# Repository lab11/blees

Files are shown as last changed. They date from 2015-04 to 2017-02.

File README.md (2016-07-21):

BLEES
=====

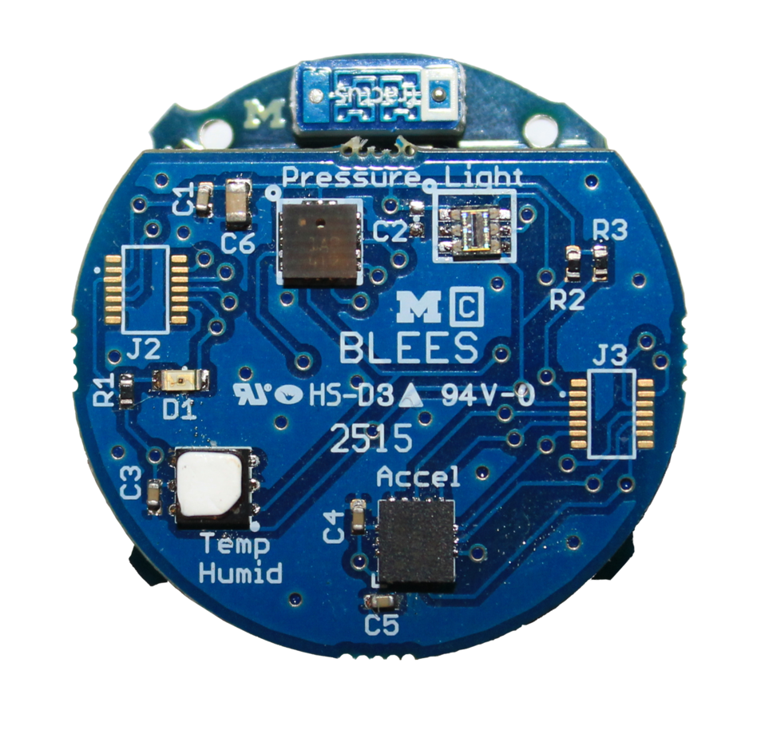
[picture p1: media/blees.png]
BLEES

BLEES: Bluetooth Low Energy Environment Sensors.
<br /><br />
BLEES is a 1 inch round sensor tag for sensing the ambient environment. It monitors
temperature, humidity, light, pressure, and movement and reports its readings
over BLE.
<br /><br /><br />

Hardware
--------
The BLEES hardware is a small, once inch round sensor board that mounts onto a [Squall](https://github.com/helena-project/squall) BLE sensor tag. The board 
currently has four sensors:

1. Temperature and Humidity (Si7021)
2. Pressure (LPS331AP)
3. Light (TSL2561)
4. Accelerometer (ADXL362)

The BLEES hardware is located in the `hardware` directory, where you can find
the Eagle design files.

Software
--------
The [Squall](https://github.com/helena-project/squall) uses the software
located in the `software` directory. Follow the directions in the [nrf5x-base Readme]
(http://github.com/lab11/nrf5x-base#program-a-nrf51822) to
get your machine set up to build and flash the Squall.

The primary application is
[`software/apps/blees`](https://github.com/lab11/blees/tree/master/software/apps/blees).
This application samples the
sensors and makes this data available as both broadcast advertisements and the
Environmental Sensing Service for a connected device.

Data Reference
--------------
### Advertisement data
BLEES transmits advertisements every 1000 ms containing application data.
[Here's a useful BLE Advertisement
primer](http://www.argenox.com/bluetooth-low-energy-ble-v4-0-development/library/a-ble-advertising-primer/).
The advertisements come in two forms: environmental data and eddystone.
Advertisements alternate between the two evenly.

The environmental data advertised is same data as is available through the
environmental sensing service, but broadcast so several nearby devices can
access it concurrently. The data includes, in order, four bytes for pressure,
two bytes for humidity, two bytes for temperature, two bytes for light
illuminance, and one byte for acceleration state. An example application that
collects BLE advertisements from BLEES devices and displays the data can be
found at `data_collection/advertisements/blees_adv.js`

[Eddystone](https://github.com/google/eddystone) is a protocol for connecting
BLE devices to Internet resources. BLEES advertises the URL of an application
that can be interpreted by the Summon framework in order to automatically
generate a user interface. (see next heading)

### Environmental Sensing Service
BLEES is also connectable and supports the Environmental Sensing Service. While
connected to, it continues to advertise, but only one connection at a time is
allowed. The environmental sensing service is defined by the
[BLE SIG](https://www.bluetooth.org/en-us/specification/assigned-numbers/environmental-sensing-service-characteristics).

Summon App
----------
[Summon](https://github.com/lab11/summon) is a UI application for BLE devices.
Rather than requiring every user
to install a new app for every BLE device, Summon allows BLE devices to
point to their own HTML/JS based interface and loads it in a single
application. BLEES supports the summon architecture and provides
a Summon application.

Cloning
-------
To clone both this repository and the required submodules,
clone with the `--recursive` option: 
`git clone --recursive git@github.com:lab11/blees.git`

Otherwise, you can initialize the submodule and keep submodules up to
date by doing `git submodule update --init --recursive`

If you think all of this is ridiculous and git should just handle submodules automatically, use this:
https://gist.github.com/brghena/fc4483a2df83c47660a5

Other Hardware
--------------

Included in this repo are:

### Blink

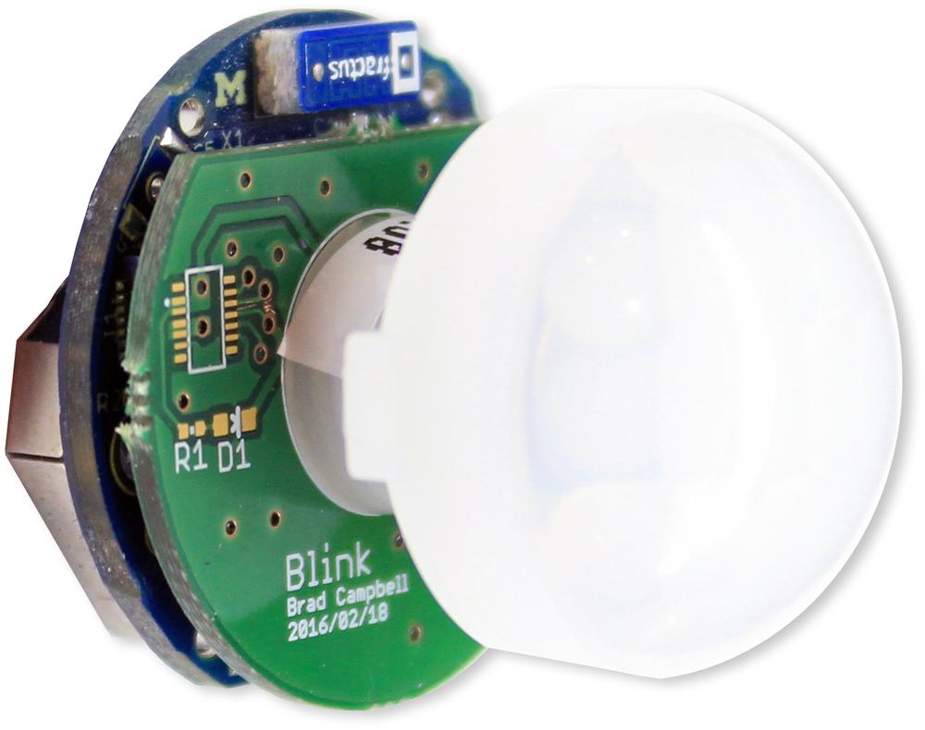
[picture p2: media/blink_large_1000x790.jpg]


Blink is a PIR sensor that is also based on Squall. Like BLEES, it supports Summon.
The nRF51822 app is [here](https://github.com/lab11/blees/tree/master/software/apps/blink).

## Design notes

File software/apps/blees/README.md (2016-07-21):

BLEES App
=========

This app provides the Environmental Sensing Service for BLEES.

Programming
-----------

    make flash ID=c0:98:e5:30:00:01

Advertisement
-------------

BLEES alternates between advertising environmental data and the
[Eddystone protocol](https://github.com/google/eddystone). It works with the
[Summon](https://github.com/lab11/summon) project that provides a browser-based
UI for BLE devices.

### Data Format

Manufacturer specific data in the advertisement:

| Index | Bytes | Description |
| ----- | --- | --- |
| 0 | `0x07` | Length |
| 1 | `0xff` | Header for manufacturer specific data  |
| 2 | `0x02e0` | University of Michigan manufacturer ID |
| 4 | `0x12` | Service identifier for BLEES data |
| 5-8 | `0x00000000` | Pressure in deci-pascals |
| 8-9 | `0x0000` | Humidity in centi-percent |
| 10-11 | `0x0000` | Temperature in centi-degrees Celsius |
| 12-13 | `0x0000` | Light in lux |
| 14 | `0x00` | Acceleration as explained below |
| 15-18 | `0x00000000` | Sequence number |

*Acceleration* is defined as boolean flags with `bit 0` indicating acceleration
in the last minute and `bit 4` indicating current acceleration.

Ex: 0x01 = acceleration in the last minute, but not currently

### Eddystone URL

Change the `PHYSWEB_URL` define to change where the BLEES Eddystone URL points to.

Services
--------

Standard environmental sensing service [ESS](https://www.bluetooth.org/en-us/specification/assigned-numbers/environmental-sensing-service-characteristics)

How To Change Acceleration
--------------------------
main.c:510 - change variable act_thresh to set the activity threshold
main.c:514 - change variable a_time to set the amount of samples required to be above threshold for a trigger

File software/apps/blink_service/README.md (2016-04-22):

Blink App
=========

Advertise Eddystone and manufacturer specific data when motion is detected.

Hardware
--------

Squall with a digital PIR sensor attached to pin 25.

Data Format
-----------

Manufacturer specific data in the advertisement:

| Index | Bytes | Description |
| ----- | --- | --- |
| 0 | `0x07` | Length |
| 1 | `0xff` | Header for manufacturer specific data  |
| 2 | `0x02e0` | University of Michigan manufacturer ID |
| 4 | `0x13` | Service identifier for Blink data |
| 5 | `0x00` | 0 if no motion right now, 1 if motion  |
| 6 | `0x00` | 0 if no motion since last advertisement packet, 1 if motion in that time |
| 7 | `0x00` | 0 if no motion in the last minute, 1 if motion |

Parsed Data Format
------------------

If Blink is used with a [SwarmGateway](https://github.com/terraswarm/urban-heartbeat-kit),
that gateway will be able to parse Blink packets. The resulting JSON object will
be:

```
{
	"device": "Blink",
	"id": "c098e59000xx",
	"current_motion": true|false,
	"motion_since_last_adv": true|false,
	"motion_last_minute": true|false
}
```

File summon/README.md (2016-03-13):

Summon Apps
===========

[Summon](https://github.com/lab11/summon) is a browser for physical things,
and BLEES comes with HTML/JS applications that Summon supports.

- `blees-app`: Full featured app for both reading and configuring BLEES devices.
- `bless-demo`: Pared down version of the full app with less options. Designed
for quicker viewing in a demo setting.

### Blink

Blink also has a Summon app in the `squall-pir` folder.

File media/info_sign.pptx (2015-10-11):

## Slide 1


BLEES

Indoor Ambient Sensing

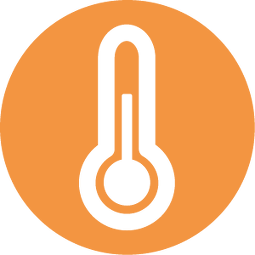
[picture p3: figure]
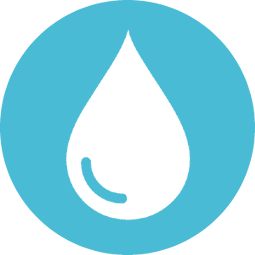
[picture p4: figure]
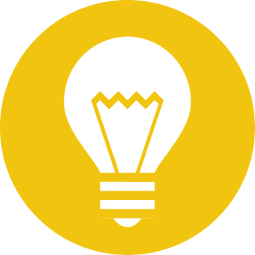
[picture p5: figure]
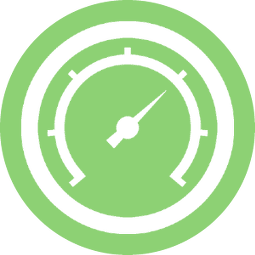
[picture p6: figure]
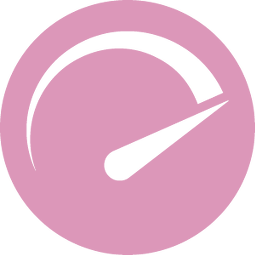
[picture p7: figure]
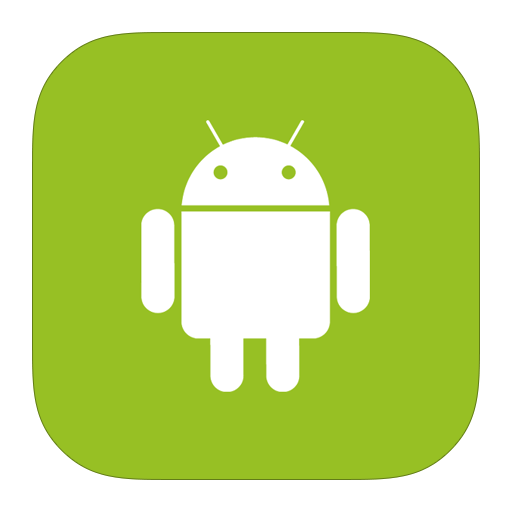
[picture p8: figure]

Download the app!

Summon App for Android

UI discovery for the IoT

Also works with
- PowerBlade
- PolyPoint

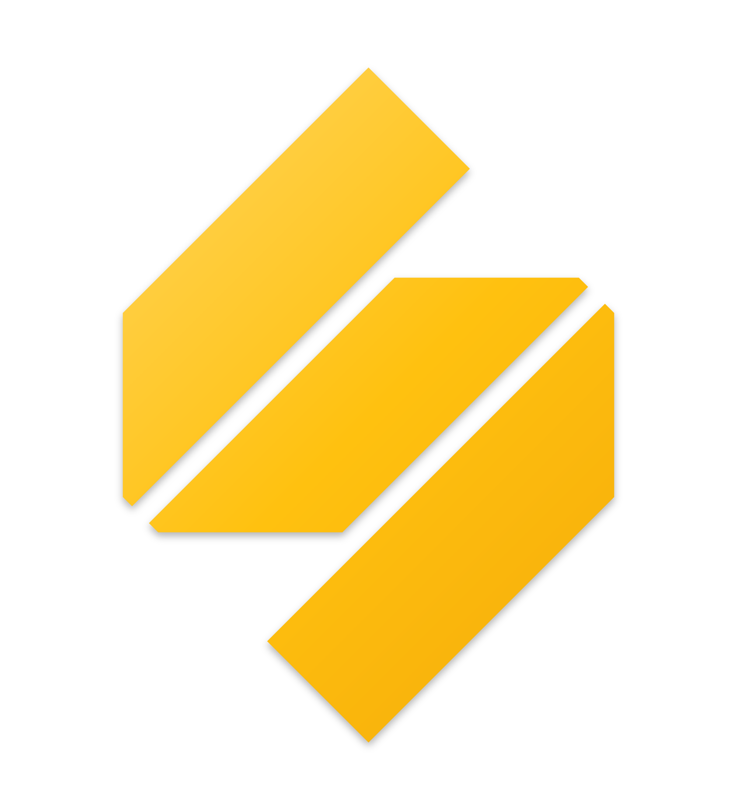
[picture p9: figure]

Search “Summon Lab11” on the Google Play store

https://github.com/lab11/blees
https://github.com/lab11/summon

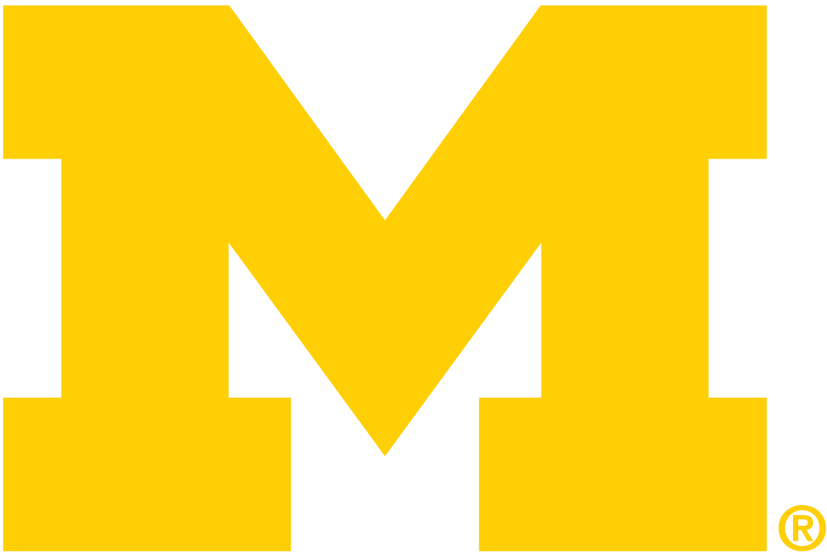
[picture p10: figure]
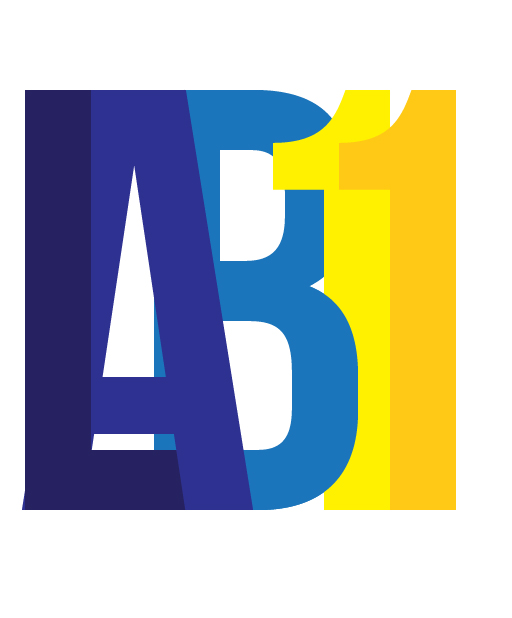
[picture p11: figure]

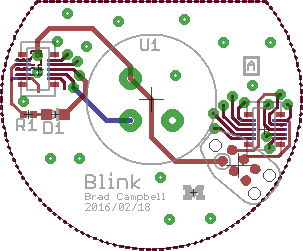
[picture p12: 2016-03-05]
hardware/blink/rev_a/blink_pcb.png

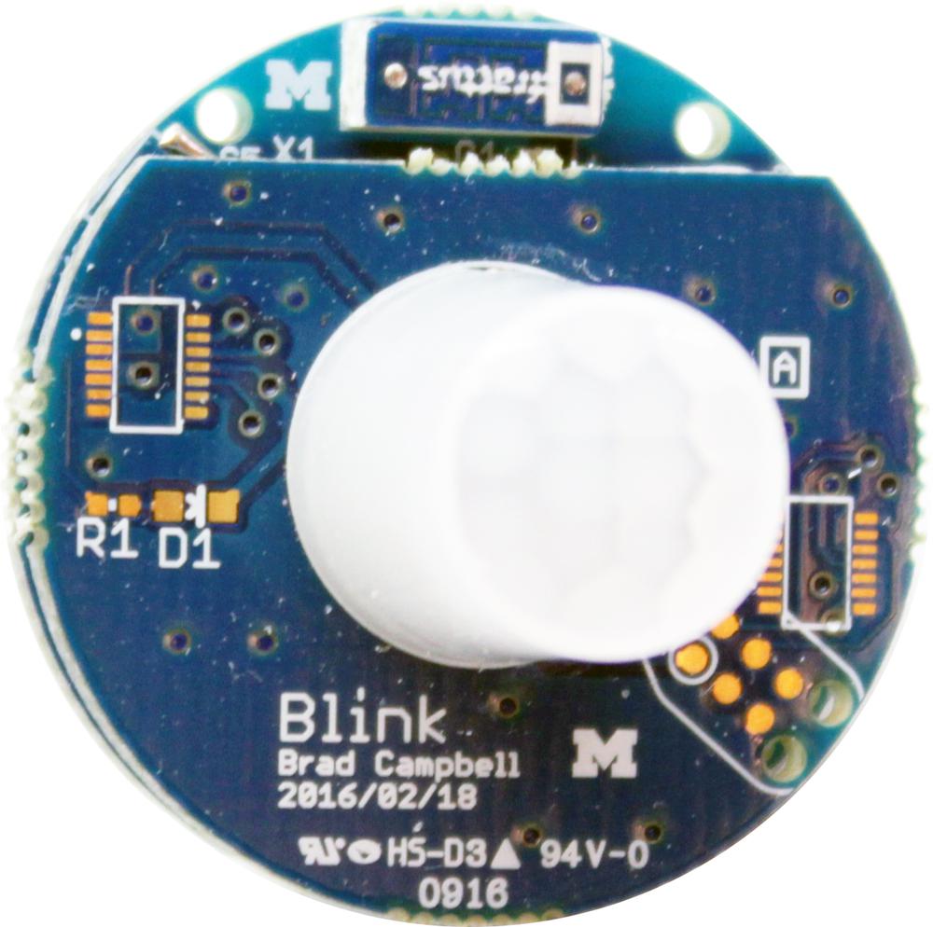
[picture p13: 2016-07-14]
media/blink_small_1000x994.jpg

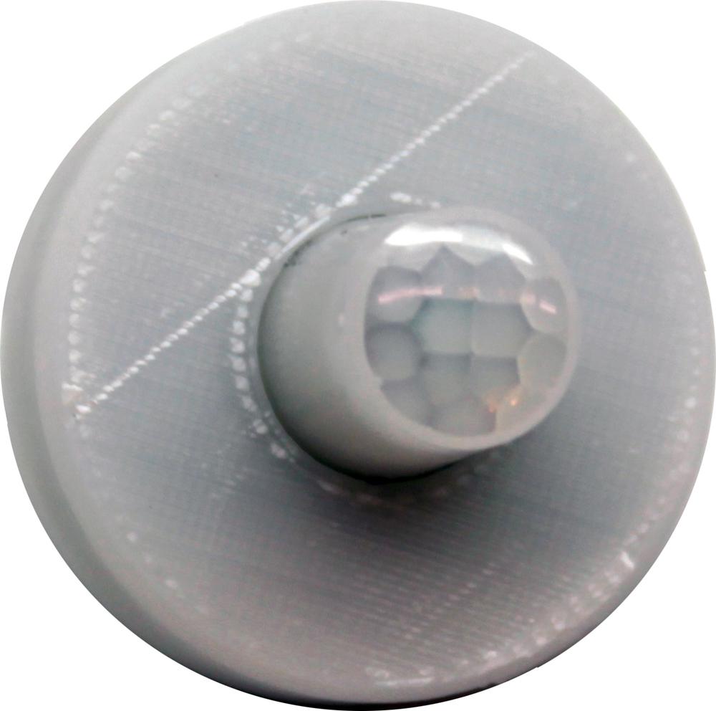
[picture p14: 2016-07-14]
media/blink_small_case_1000x992.jpg

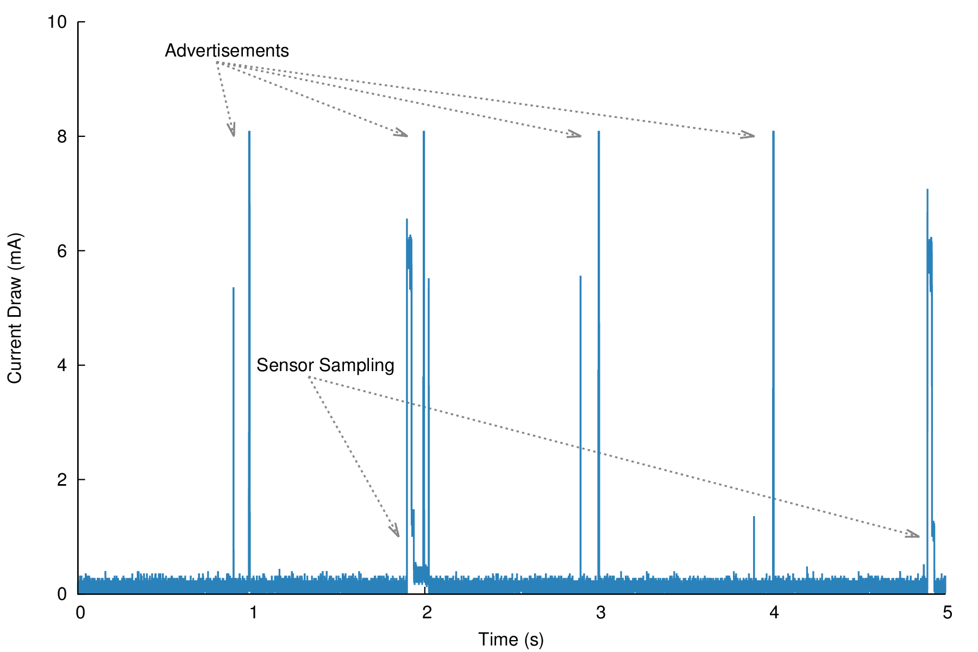
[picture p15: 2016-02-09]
media/current_trace/blees_current_trace.png

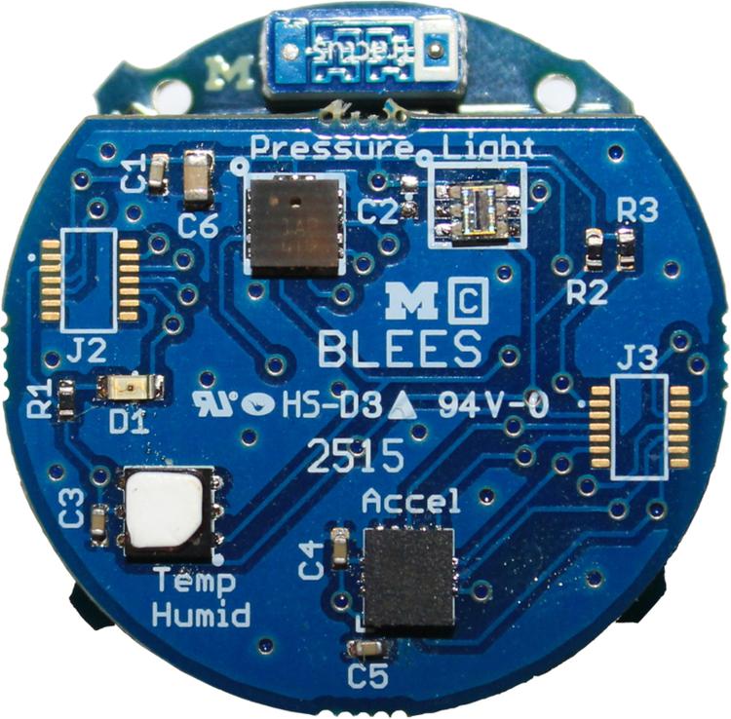
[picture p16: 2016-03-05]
media/blees_750x738.jpg

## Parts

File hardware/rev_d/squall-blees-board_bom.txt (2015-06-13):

# Bill of Materials
# Converted from squall-blees-board_bom.xlsx
# Generated by bom_to_text.py

Qty  Value                   Device                  Package        Parts               Description                                                    DIGIKEY               MOUSER               NEWARK
5    100nF                   CAPACITOR               0402_CAP       C1, C2, C3, C4, C5  0402 Capacitor                                                 1276-1442-6-ND                             
1    10uF                    CAPACITOR0603_CAP       0603_CAP       C6                  0603 Capacitor                                                 1276-1119-6-ND                             
1    BLUE                    LED0603                 LED-0603       D1                  LEDs                                                           160-1647-1-ND                              
2    SQUALL_HEADER           SQUALL_HEADER           SQUALL_HEADER  J1                  Header for a sensor board on top of the Squall BLE tag board.  H11617CT-ND                                
2    HIROSE-DF40C-10DP-0.4V  HIROSE-DF40C-10DP-0.4V  2X5/SMD/0.4MM  J2, J3              DF40 Series Header - 0.4MM Pitch                               H11616CT-ND           798-DF40C10DP0.4V51  68X2585
1    1k                      RESISTOR0402_RES        0402_RES       R1                  0402 Resistor                                                  RHM1.0KCECT-ND                             
2    10k                     RESISTOR0402_RES        0402_RES       R2, R3              0402 Resistor                                                  RHM10.0KCDCT-ND                            
1    LPS331APQFN             LPS331APQFN             HCLGA-16L      U1                  LPS331AP pressure sensor                                                                                  52X6707
1    TSL2561DFN              TSL2561DFN              DFN2           U2                  TSL2561 light to digital converter                             TSL2561-FNDKR-ND                           
1    Si7021                  Si7021                  DFN            U3                  Si7021 temperature/humidity sensor                             336-2542-1-ND                              
1    ADXL362                 ADXL362                 ADXL362        U4                  Micropower 3-axis accelerometer                                ADXL362BCCZ-R2DKR-ND

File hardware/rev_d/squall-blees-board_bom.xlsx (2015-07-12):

 | Qty | Value | Device | Package | Parts | Description | DIGIKEY | MOUSER | NEWARK
b | 5 | 100nF | CAPACITOR | 0402_CAP | C1, C2, C3, C4, C5 | 0402 Capacitor | 1276-1442-6-ND
b | 1 | 10uF | CAPACITOR0603_CAP | 0603_CAP | C6 | 0603 Capacitor | 1276-1119-6-ND
l | 1 | BLUE | LED0603 | LED-0603 | D1 | LEDs | 160-1647-1-ND
b | 2 | SQUALL_HEADER | SQUALL_HEADER | SQUALL_HEADER | J1 | Header for a sensor board on top of the Squall BLE tag board. | H11617CT-ND
s | 2 | HIROSE-DF40C-10DP-0.4V | HIROSE-DF40C-10DP-0.4V | 2X5/SMD/0.4MM | J2, J3 | DF40 Series Header - 0.4MM Pitch | H11616CT-ND | 798-DF40C10DP0.4V51 | 68X2585
s | 1 | 1k | RESISTOR0402_RES | 0402_RES | R1 | 0402 Resistor | RHM1.0KCECT-ND
b | 2 | 10k | RESISTOR0402_RES | 0402_RES | R2, R3 | 0402 Resistor | RHM10.0KCDCT-ND
b | 1 | LPS331APQFN | LPS331APQFN | HCLGA-16L | U1 | LPS331AP pressure sensor |  |  | 52X6707
b | 1 | TSL2561DFN | TSL2561DFN | DFN2 | U2 | TSL2561 light to digital converter | TSL2561-FNDKR-ND
b | 1 | Si7021 | Si7021 | DFN | U3 | Si7021 temperature/humidity sensor | 336-2542-1-ND
b | 1 | ADXL362 | ADXL362 | ADXL362 | U4 | Micropower 3-axis accelerometer | ADXL362BCCZ-R2DKR-ND
 |  | (b)lees
 |  | (s)quall
 |  | (l)ed box
 |  | (o)bserver
 |  | (x) did not populate

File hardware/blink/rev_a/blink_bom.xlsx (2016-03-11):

Qty | Value | Device | Package | Parts | Description | DIGIKEY | MOUSER | NEWARK
DNP | BLUE | LED0603 | LED-0603 | D1 | LEDs
2 | SQUALL_HEADER | SQUALL_HEADER | SQUALL_HEADER | J1 | Header for a sensor board on top of the Squall BLE tag board. | H11617CT-ND
DNP | HIROSE-DF40C-10DP-0.4V | HIROSE-DF40C-10DP-0.4V | 2X5/SMD/0.4MM | J2, J3 | DF40 Series Header - 0.4MM Pitch | H11616CT-ND | 798-DF40C10DP0.4V51 | 68X2585
DNP | 1kΩ | RESISTOR0402_RES | 0402_RES | R1 | Resistor
1 | AMN41121 | AMN41121 | AMN2 | U1 | Passive infrared human detection sensor with built-in amp. | 255-2651-ND

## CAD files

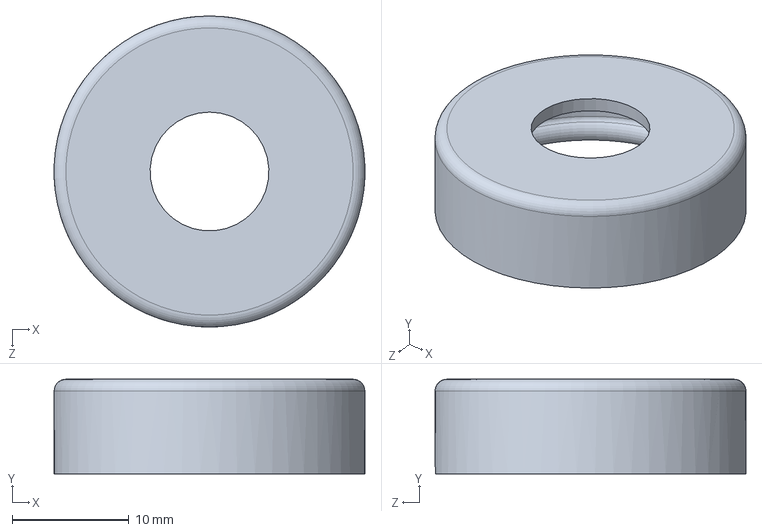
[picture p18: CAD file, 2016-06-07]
hardware/case/blink_case.SLDPRT
26.6 x 8.09 x 26.6 mm

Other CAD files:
hardware/case/blink_case_v1.STL

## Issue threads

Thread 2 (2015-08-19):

Build issue

bradjc, 2015-08-19:
```
In file included from main.c:32:0:
/home/bradjc/code/nrf/sdk9/components/ble/device_manager/device_manager.h:72:33: fatal error: device_manager_cnfg.h: No such file or directory
 #include "device_manager_cnfg.h"
                                 ^
compilation terminated.
```

Perhaps a file isn't committed?

brghena, 2015-08-19:
You include device_manager_cnfg.h and device_manager.h in main.c. You might look into whether you need those and why.

brghena, 2015-08-27:
Fixed

Closed 2015-08-27.

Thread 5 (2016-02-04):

Strong magnets vs. the battery holder

vielmetti, 2016-02-04:
I have a set of strong magnets that were originally sourced for an "LED throwie" project. The idea is that you wire up a little circuit, attach a magnet, and then throw the device to hope to stick on a wall or sign or whatever.

The magnets that I have stick nicely to the BLEES, but the design of the battery holder is such that the device will lose power when stuck to this magnet because the holder has just enough wiggle room that when the battery is stuck to the magnet it gets disconnected from the device.

If I read it right, the Squall is the actual place where the issue is, and I was looking for the bill of materials for that device and didn't see it in this repo.

prabaldutta, 2016-02-04:
See:
http://lab11.eecs.umich.edu/content/pcb/squall/a/squall.pdf
and
http://lab11.eecs.umich.edu/content/pcb/squall/a/squall_a_2014-10-08.zip
linked from:
http://lab11.eecs.umich.edu/pcb.html

- Prabal

On Thu, Feb 4, 2016 at 12:05 AM, Edward Vielmetti <notifications@github.com>
wrote:

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

jonesnl, 2016-02-04:
In addition to the links above, here's the link to the Squall Github repo: https://github.com/helena-project/squall

bradjc, 2016-06-06:
Our solution right now is to put more solder on the GND pad under the batter holder. Seems to work.

Closed 2016-06-06.

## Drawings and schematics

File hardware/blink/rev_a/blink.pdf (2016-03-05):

## Squall Header

Left Header | Right Header

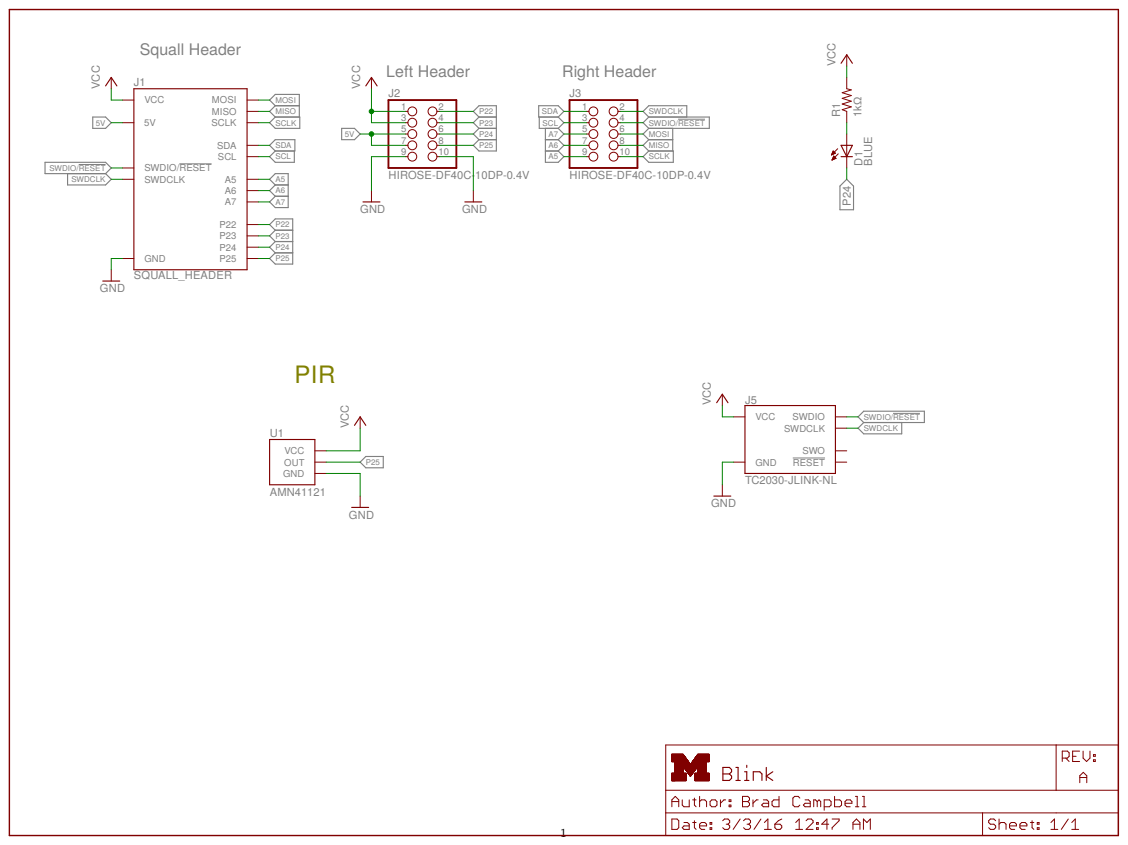
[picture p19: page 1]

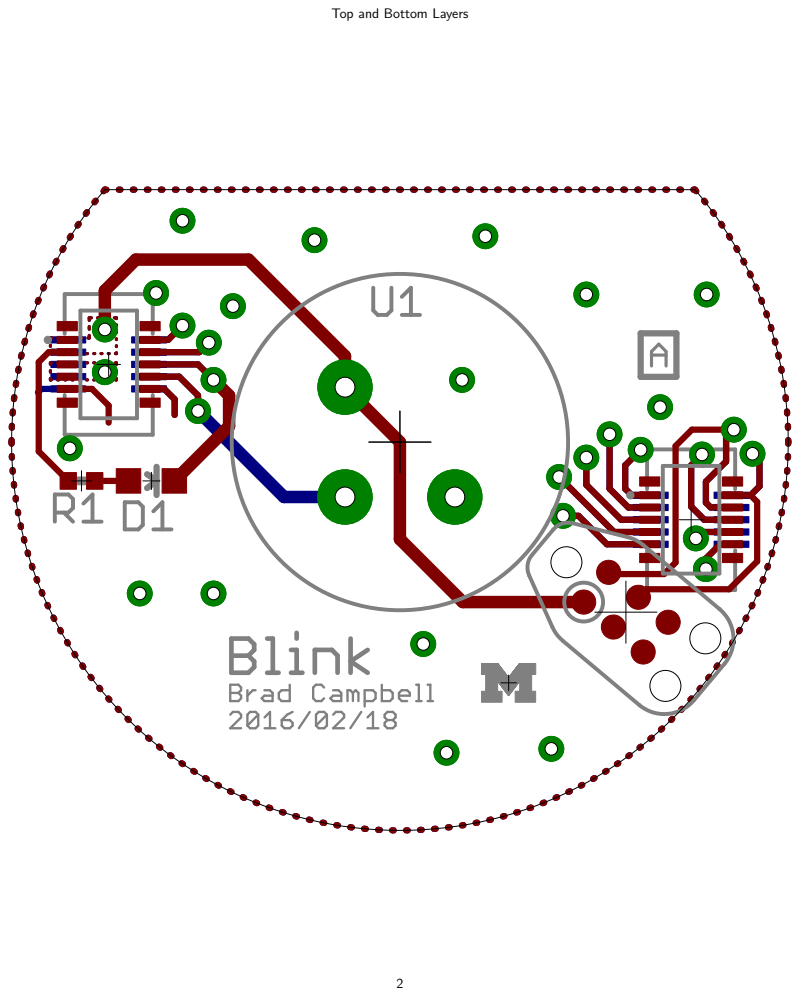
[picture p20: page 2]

Top and Bottom Layers

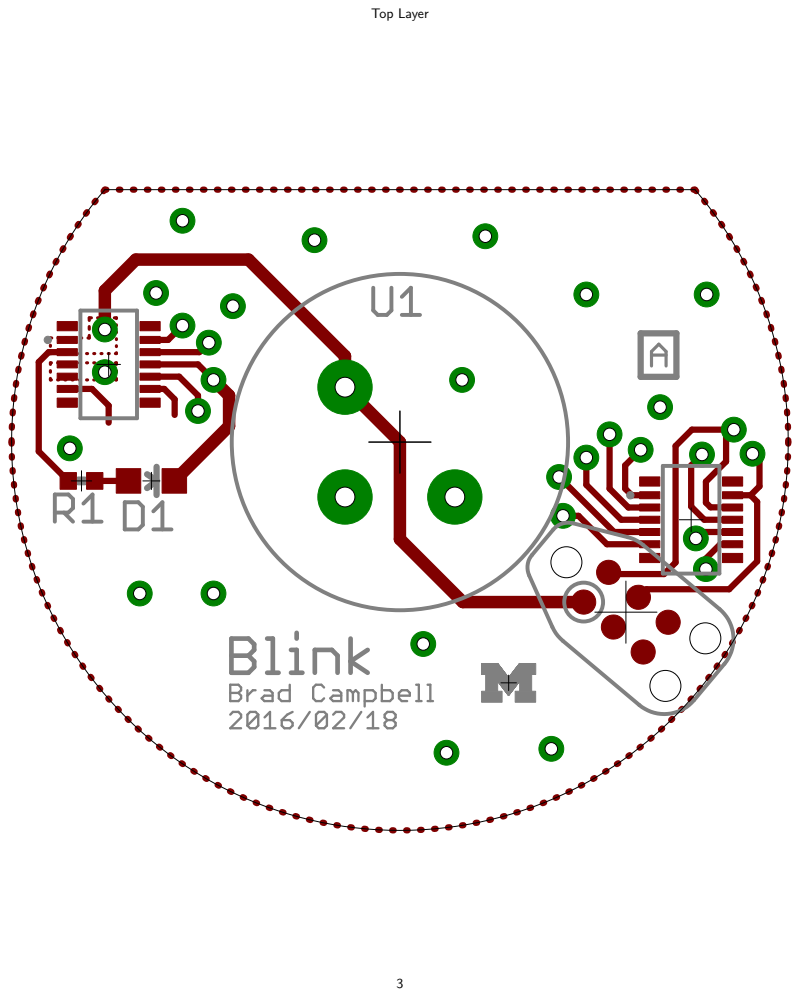
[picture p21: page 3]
Top Layer

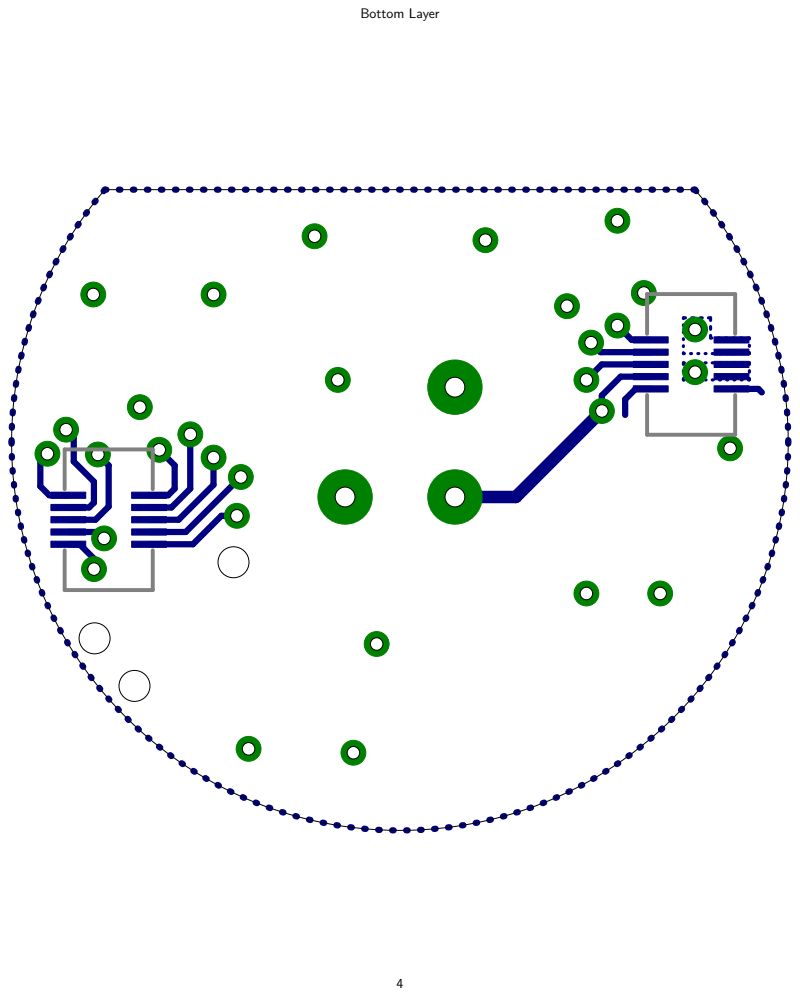
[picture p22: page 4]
Bottom Layer

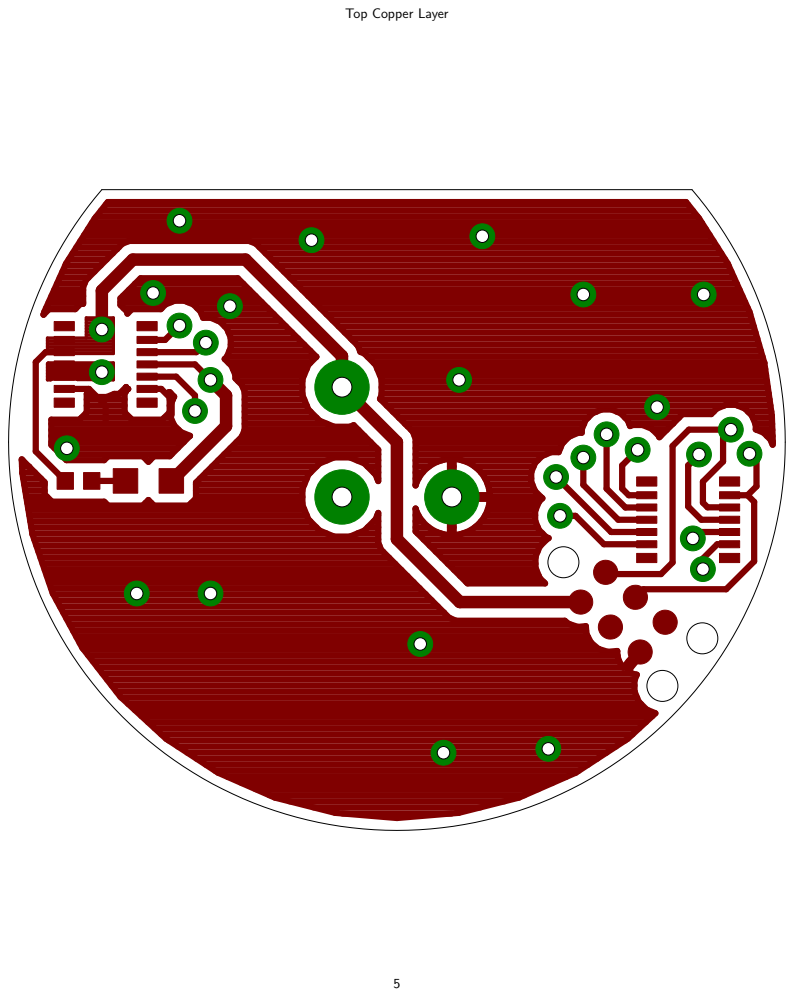
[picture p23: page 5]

Top Copper Layer

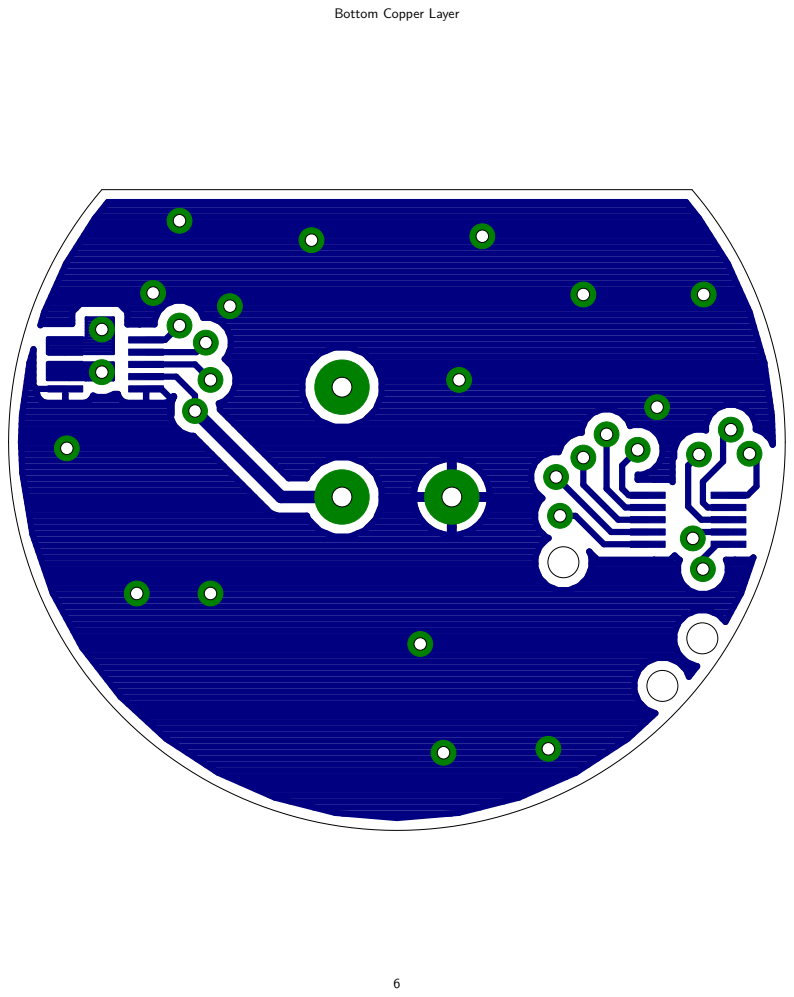
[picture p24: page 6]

Bottom Copper Layer

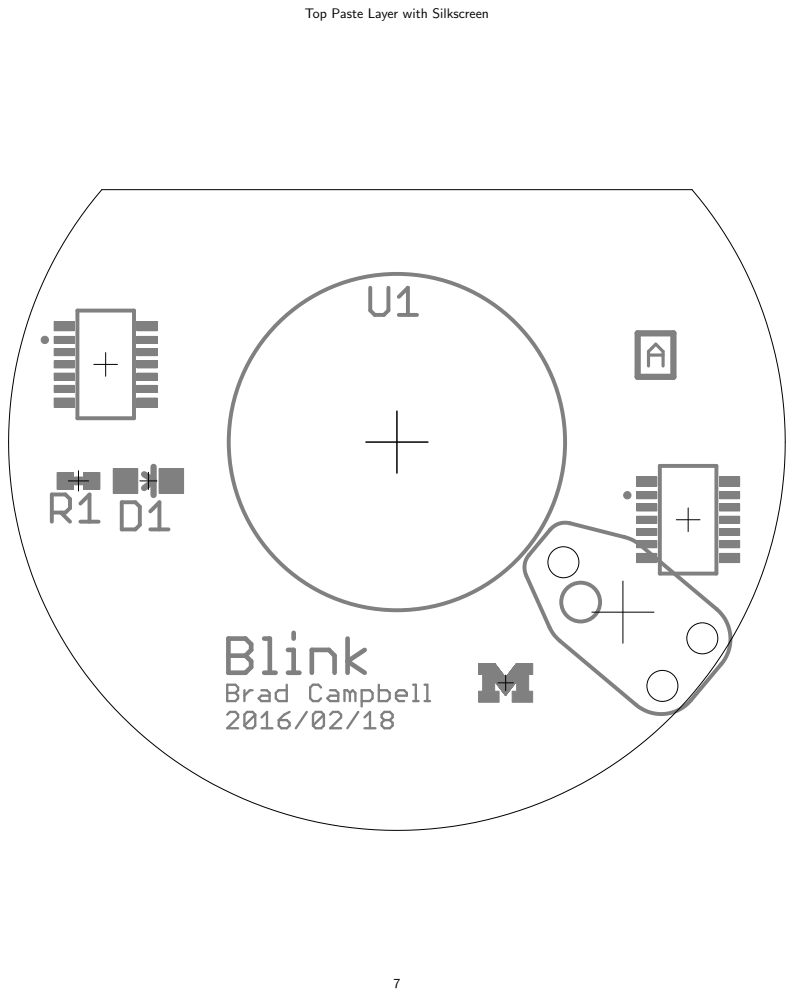
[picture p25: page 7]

Top Paste Layer with Silkscreen

Bottom Paste Layer with Silkscreen

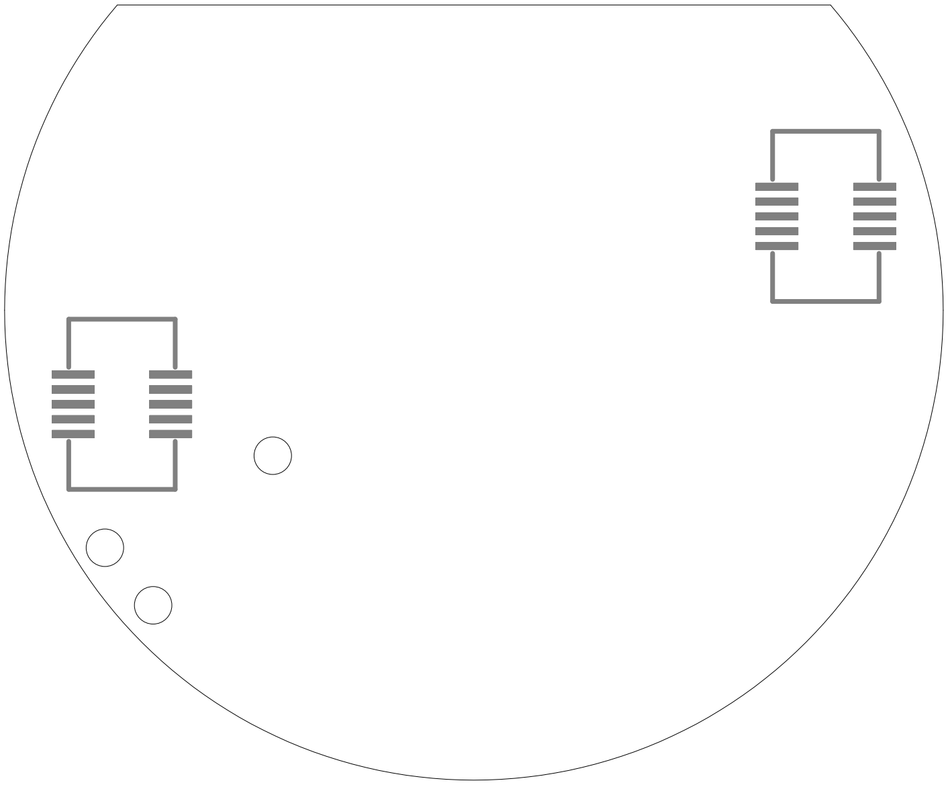
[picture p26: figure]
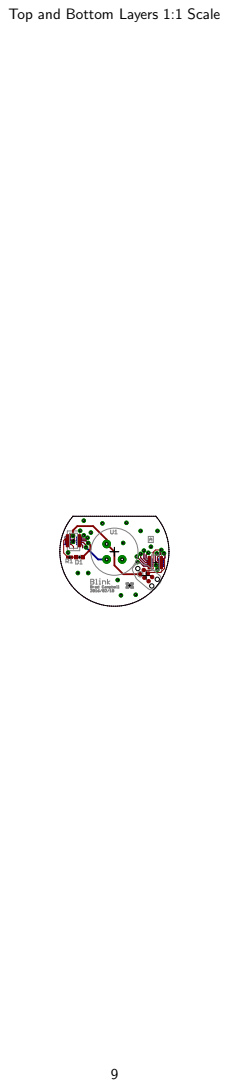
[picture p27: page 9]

Top and Bottom Layers 1:1 Scale

Top Layer 1:1 Scale

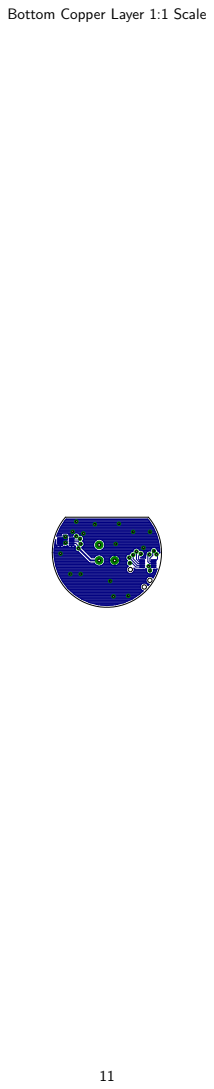
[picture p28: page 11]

Bottom Copper Layer 1:1 Scale

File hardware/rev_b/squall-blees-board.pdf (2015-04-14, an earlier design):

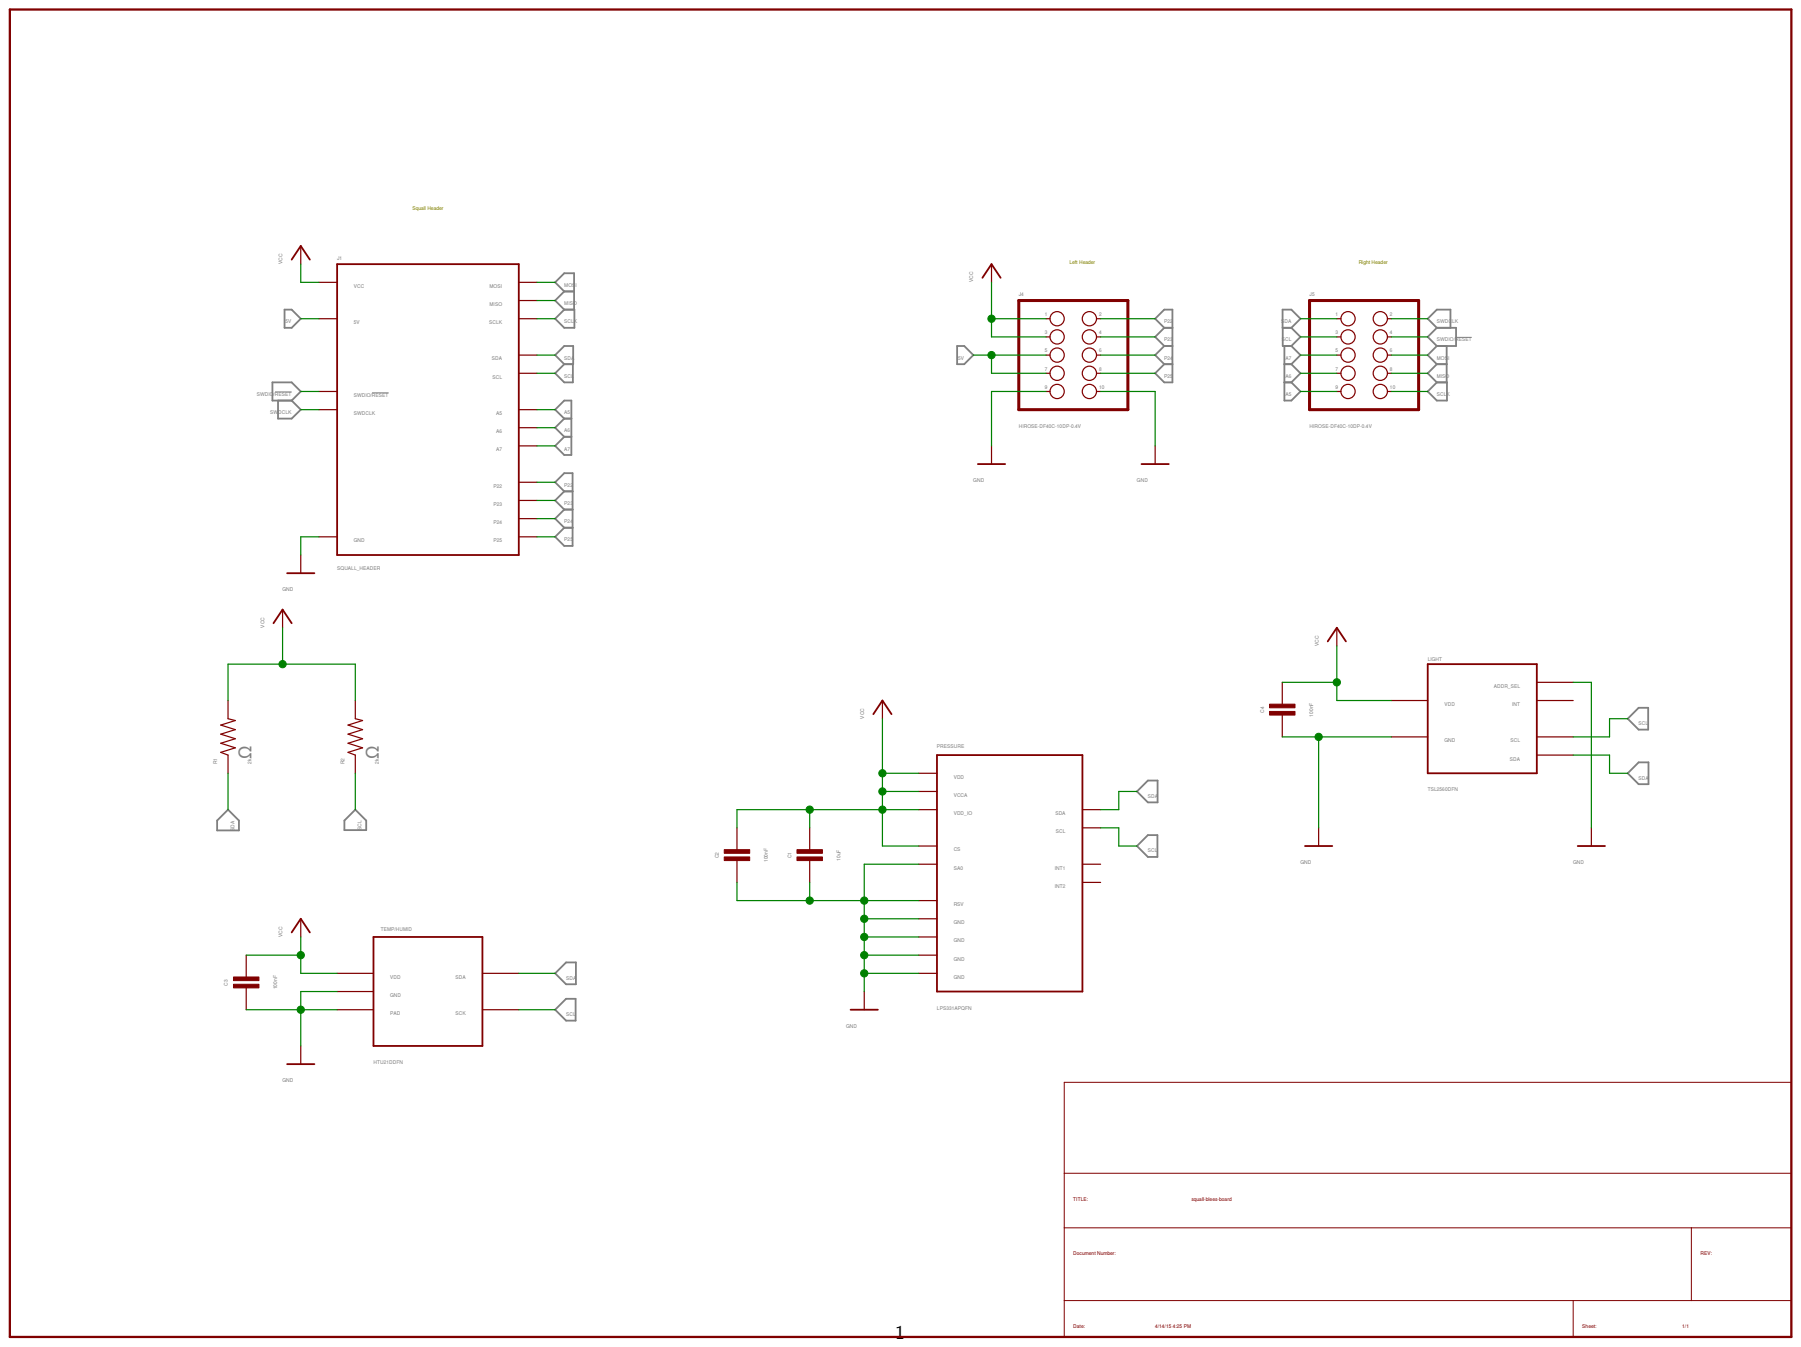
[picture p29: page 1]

Document Number: | REV:

Date: 4/14/15 4:25 PM | Sheet: 1/1

# Top and Bottom Layers

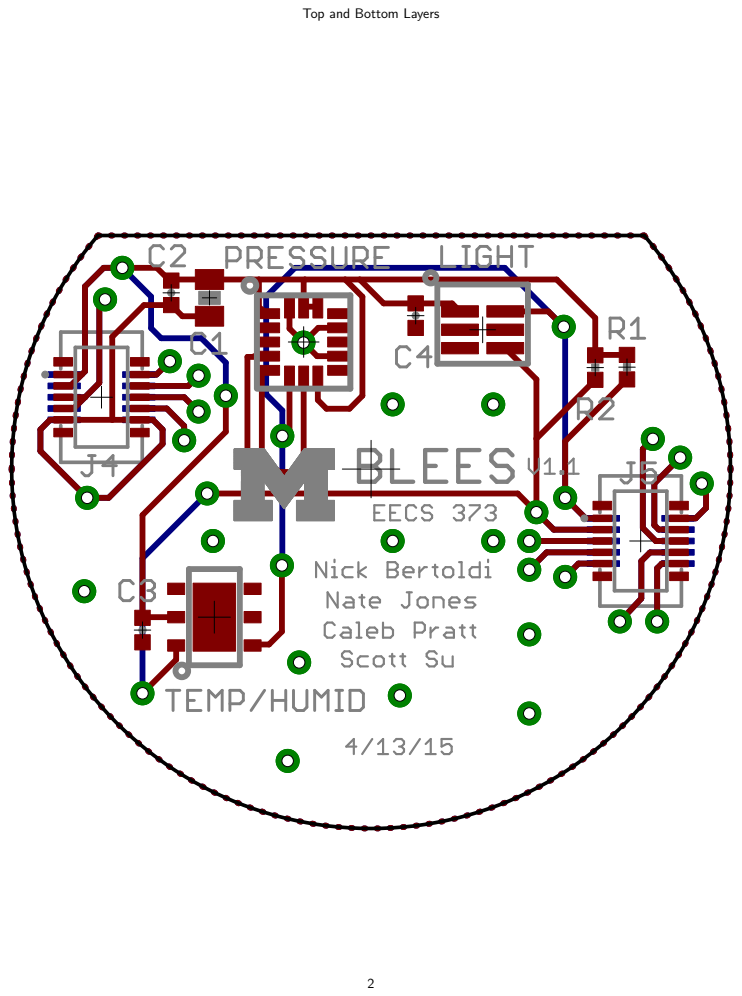
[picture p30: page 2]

# Top Layer


# Bottom Layer


# Top Copper Layer


# Bottom Copper Layer


# Top Paste Layer with Silkscreen


# Bottom Paste Layer with Silkscreen


# Top and Bottom Layers 1:1 Scale


# Top Layer 1:1 Scale

# Bottom Copper Layer 1:1 Scale


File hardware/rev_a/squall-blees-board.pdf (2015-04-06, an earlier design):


Document Number: | REV:

Date: 4/6/15 3:59 PM | Sheet: 1/1

# Top and Bottom Layers


# Top Layer


# Bottom Layer


# Top Copper Layer


# Bottom Copper Layer


# Top Paste Layer with Silkscreen


# Bottom Paste Layer with Silkscreen


# Top and Bottom Layers 1:1 Scale


# Top Layer 1:1 Scale

# Bottom Copper Layer 1:1 Scale
















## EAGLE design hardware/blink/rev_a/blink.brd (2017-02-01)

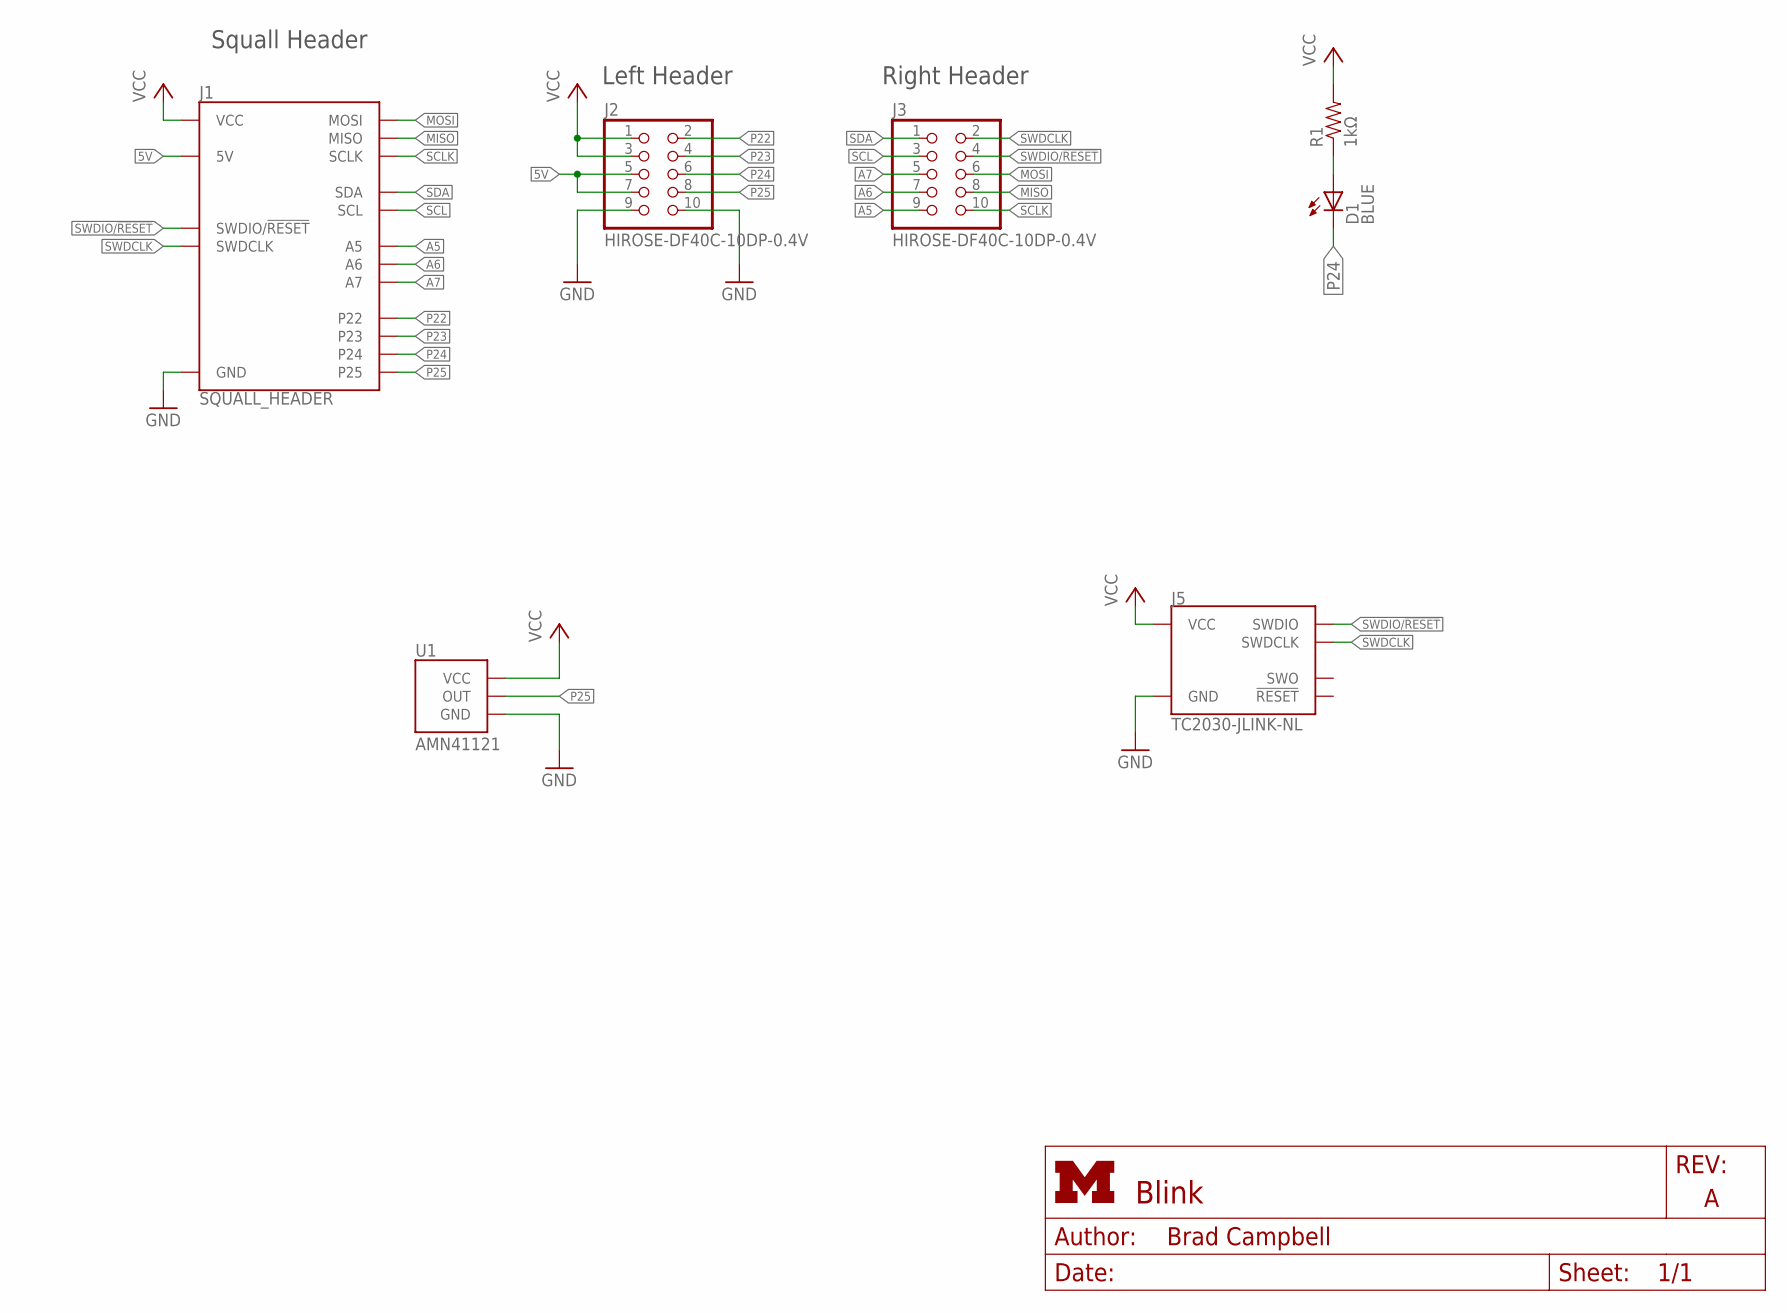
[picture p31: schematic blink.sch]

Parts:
D1: BLUE; LED-0603
J1: SQUALL_HEADER
J2, J3: HIROSE-DF40C-10DP-0.4V; 2X5/SMD/0.4MM
J5: TC2030-JLINK-NL; TC2030-IDC-NL
R1: 1kΩ; 0402_RES
U1: AMN41121; AMN2; DIGIKEY 255-3065-ND

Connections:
5V: J1.A5 (5V), J1.A7 (5V), J2.5, J2.7
A5: J1.B9 (A5), J3.9
A6: J1.B7 (A6), J3.7
A7: J1.B5 (A7), J3.5
GND: J1.A9 (GND), J1.A10 (GND), J2.9, J2.10, J5.5 (GND), U1.GND
MISO: J1.B8 (MISO), J3.8
MOSI: J1.B6 (MOSI), J3.6
unnamed: D1.A, R1.1
P22: J1.A2 (P22), J2.2
P23: J1.A4 (P23), J2.4
P24: D1.C, J1.A6 (P24), J2.6
P25: J1.A8 (P25), J2.8, U1.OUT
SCL: J1.B3 (SCL), J3.3
SCLK: J1.B10 (SCLK), J3.10
SDA: J1.B1 (SDA), J3.1
SWDCLK: J1.B2 (SWDCLK), J3.2, J5.4 (SWDCLK)
SWDIO/!RESET: J1.B4 (SWDIO/!RESET), J3.4, J5.2 (SWDIO)
VCC: J1.A1 (VCC), J1.A3 (VCC), J2.1, J2.3, J5.1 (VCC), R1.2, U1.VCC

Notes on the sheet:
Squall Header
Left Header
Right Header

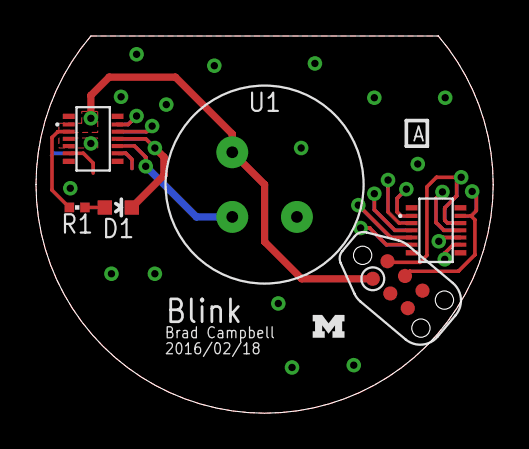
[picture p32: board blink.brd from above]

Board: 2 copper layers, 25.4 x 21.0 mm, 8 parts (0 on the bottom side), 18 nets.

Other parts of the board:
U$1: UMICH_SOLID_50MIL

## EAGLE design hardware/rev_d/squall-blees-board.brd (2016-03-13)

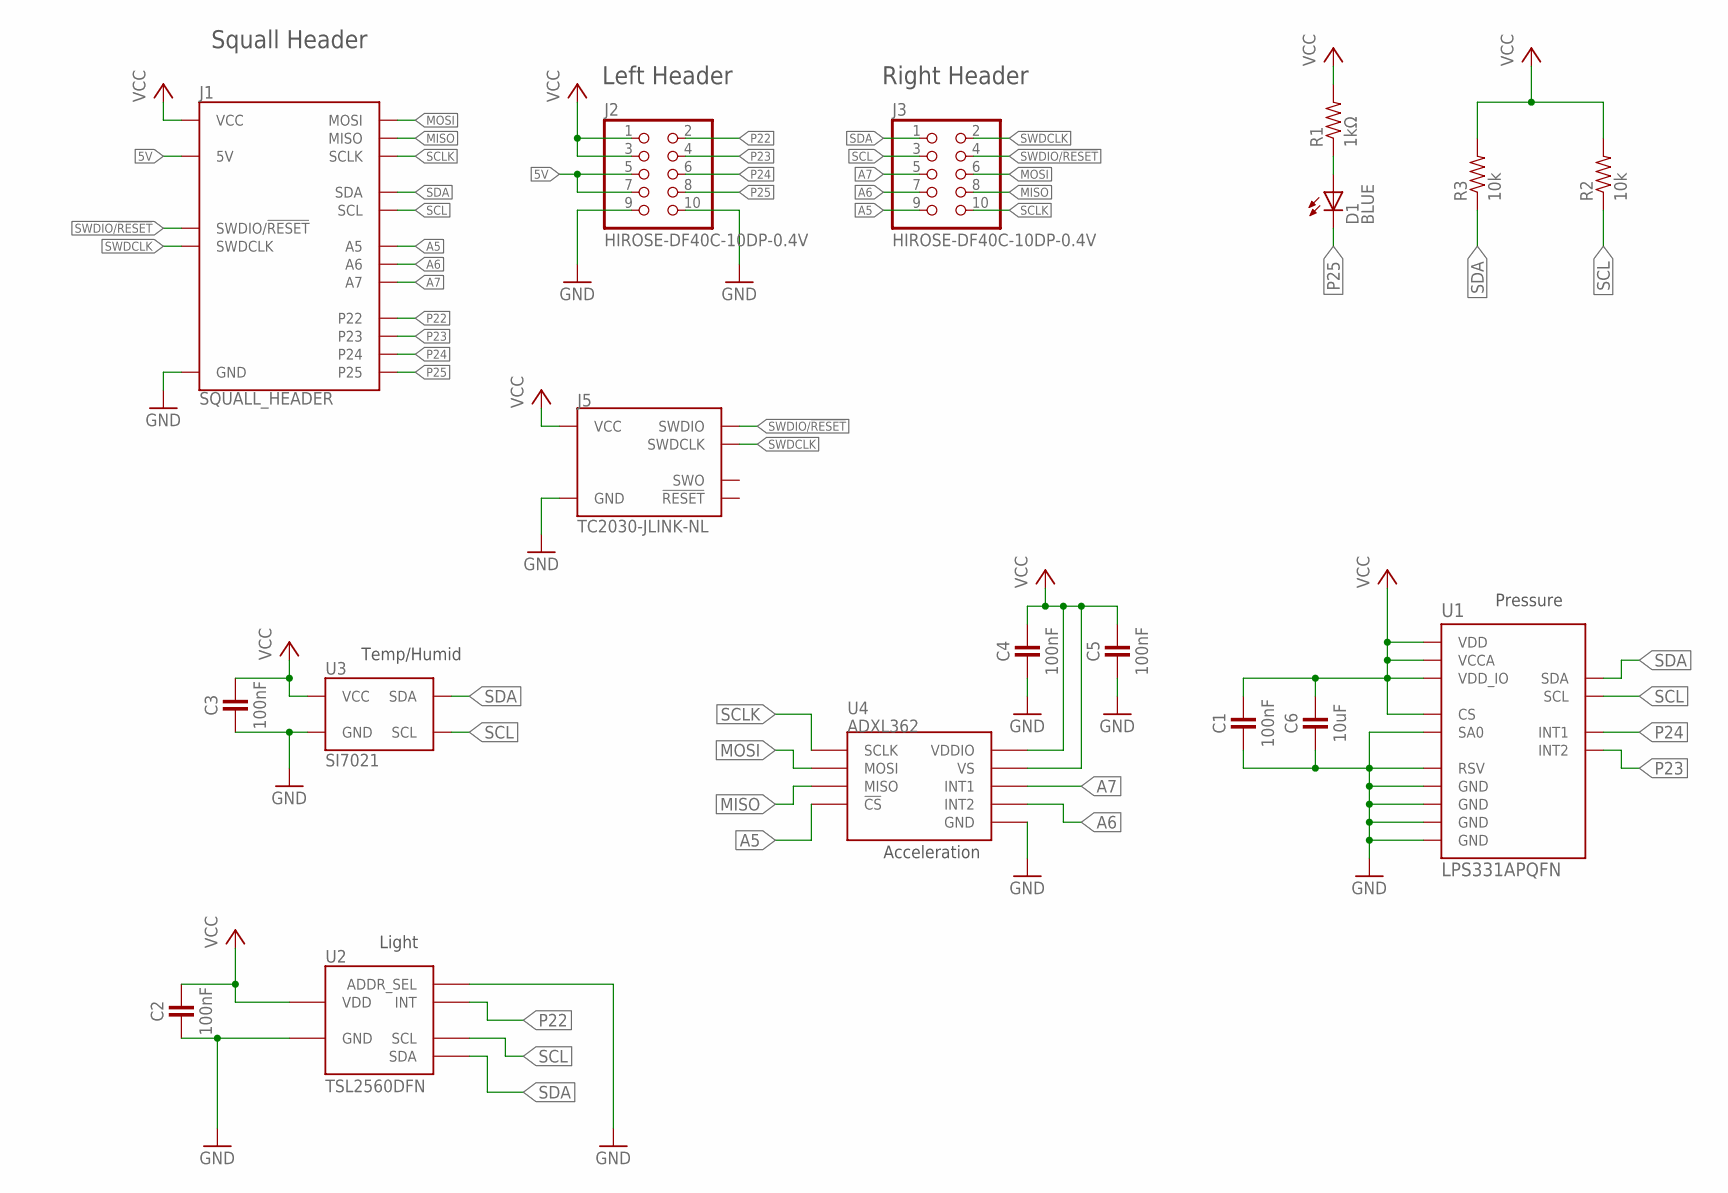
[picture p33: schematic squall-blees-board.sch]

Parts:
C1, C2, C3, C4, C5: 100nF; 0402_CAP
C6: 10uF; 0603_CAP
D1: BLUE; LED-0603
J1: SQUALL_HEADER
J2, J3: HIROSE-DF40C-10DP-0.4V; 2X5/SMD/0.4MM
J5: TC2030-JLINK-NL; TC2030-IDC-NL
R1: 1kΩ; 0402_RES
R2, R3: 10k; 0402_RES
U1: LPS331APQFN; HCLGA-16L
U2: TSL2560DFN; DFN2
U3: SI7021; DFN-6/3MM
U4: ADXL362

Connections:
5V: J1.A5 (5V), J1.A7 (5V), J2.5, J2.7
A5: J1.B9 (A5), J3.9, U4.P$8 (!CS)
A6: J1.B7 (A6), J3.7, U4.P$9 (INT2)
A7: J1.B5 (A7), J3.5, U4.P$11 (INT1)
GND: C1.2, C2.2, C3.2, C4.2, C5.2, C6.2, J1.A9 (GND), J1.A10 (GND), J2.9, J2.10, J5.5 (GND), U1.5 (GND), U1.7 (SA0), U1.10 (RSV), U1.12 (GND), U1.13 (GND), U1.16 (GND), U2.2 (ADDR_SEL), U2.3 (GND), U3.2 (GND), U4.P$12 (GND), U4.P$13 (GND), U4.P$16 (GND)
MISO: J1.B8 (MISO), J3.8, U4.P$7 (MISO)
MOSI: J1.B6 (MOSI), J3.6, U4.P$6 (MOSI)
unnamed: D1.A, R1.1
P22: J1.A2 (P22), J2.2, U2.5 (INT)
P23: J1.A4 (P23), J2.4, U1.9 (INT2)
P24: J1.A6 (P24), J2.6, U1.11 (INT1)
P25: D1.C, J1.A8 (P25), J2.8
SCL: J1.B3 (SCL), J3.3, R2.1, U1.4 (SCL), U2.4 (SCL), U3.6 (SCL)
SCLK: J1.B10 (SCLK), J3.10, U4.P$4 (SCLK)
SDA: J1.B1 (SDA), J3.1, R3.1, U1.6 (SDA), U2.6 (SDA), U3.1 (SDA)
SWDCLK: J1.B2 (SWDCLK), J3.2, J5.4 (SWDCLK)
SWDIO/!RESET: J1.B4 (SWDIO/!RESET), J3.4, J5.2 (SWDIO)
VCC: C1.1, C2.1, C3.1, C4.1, C5.1, C6.1, J1.A1 (VCC), J1.A3 (VCC), J2.1, J2.3, J5.1 (VCC), R1.2, R2.2, R3.2, U1.1 (VDD_IO), U1.8 (CS), U1.14 (VDD), U1.15 (VCCA), U2.1 (VDD), U3.5 (VCC), U4.P$1 (VDDIO), U4.P$14 (VS)

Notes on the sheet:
Squall Header
Left Header
Right Header
Pressure
Acceleration
Light
Temp/Humid

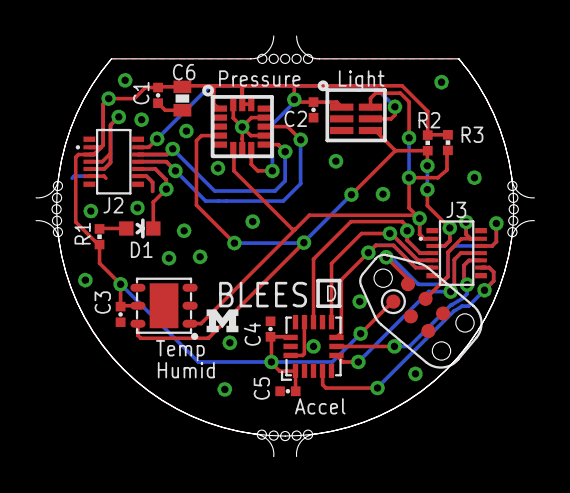
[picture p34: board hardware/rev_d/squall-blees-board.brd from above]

Board: 2 copper layers, 27.7 x 23.4 mm, 19 parts (0 on the bottom side), 18 nets.

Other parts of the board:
U$1: UMICH_SOLID_50MIL

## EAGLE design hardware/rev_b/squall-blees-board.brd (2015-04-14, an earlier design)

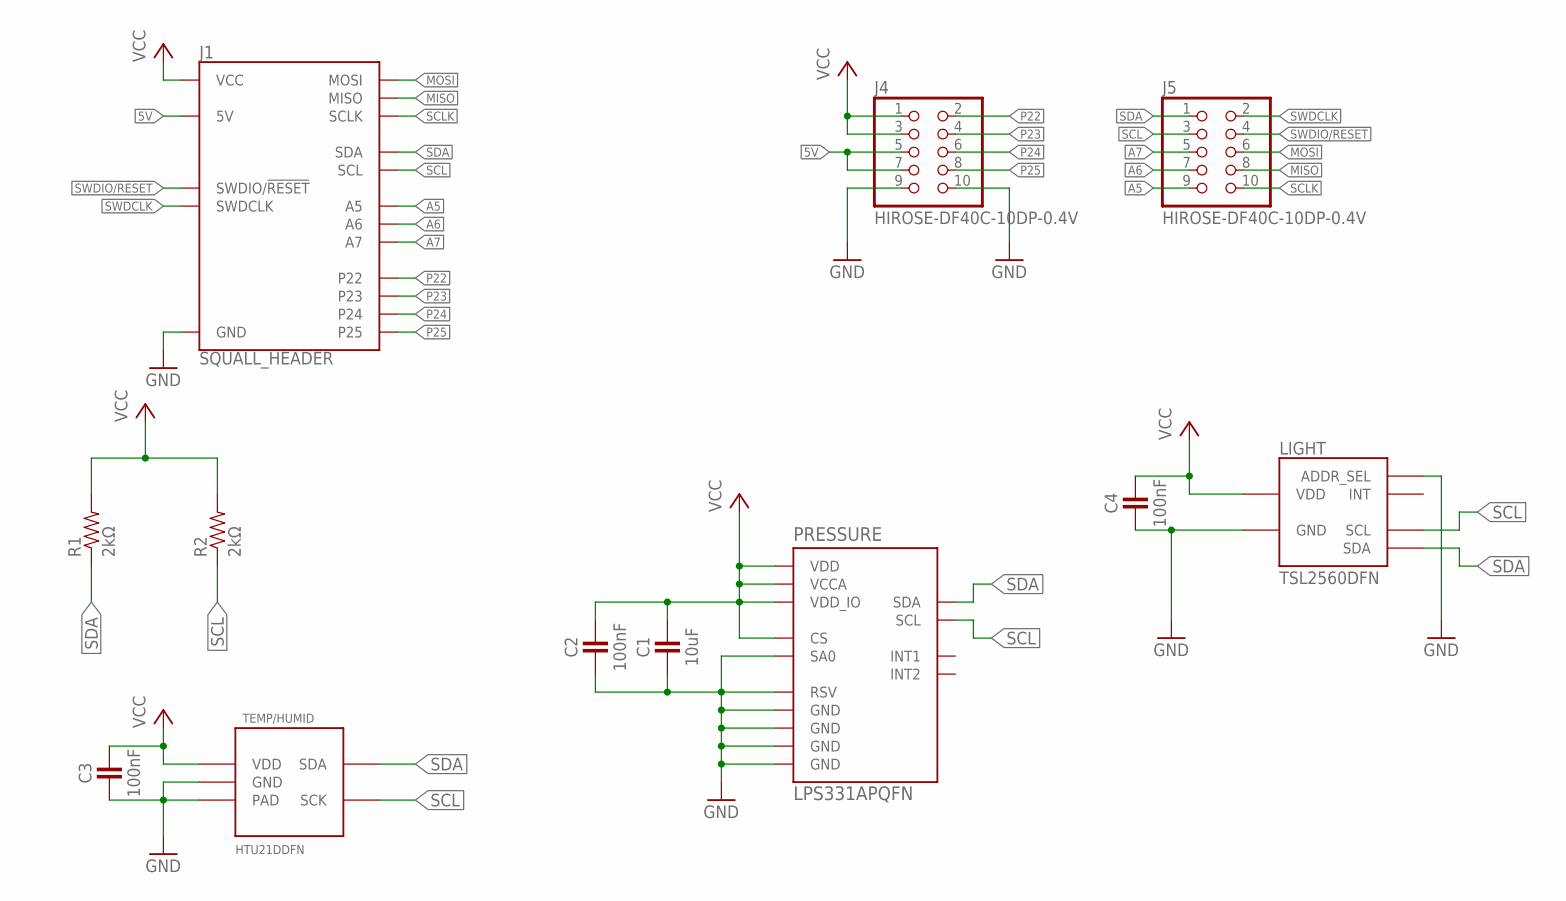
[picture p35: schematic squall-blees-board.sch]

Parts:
C1: 10uF; 0603_CAP
C2, C3, C4: 100nF; 0402_CAP
J1: SQUALL_HEADER
J4, J5: HIROSE-DF40C-10DP-0.4V; 2X5/SMD/0.4MM
LIGHT: TSL2560DFN; DFN2
PRESSURE: LPS331APQFN; HCLGA-16L
R1, R2: 2kΩ; 0402_RES
TEMP/HUMID: HTU21DDFN; DFN

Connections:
5V: J1.A5 (5V), J1.A7 (5V), J4.5, J4.7
A5: J1.B9 (A5), J5.9
A6: J1.B7 (A6), J5.7
A7: J1.B5 (A7), J5.5
GND: C1.2, C2.2, C3.2, C4.2, J1.A9 (GND), J1.A10 (GND), J4.9, J4.10, LIGHT.2 (ADDR_SEL), LIGHT.3 (GND), PRESSURE.5 (GND), PRESSURE.7 (SA0), PRESSURE.10 (RSV), PRESSURE.12 (GND), PRESSURE.13 (GND), PRESSURE.16 (GND), TEMP/HUMID.5 (GND), TEMP/HUMID.PAD
MISO: J1.B8 (MISO), J5.8
MOSI: J1.B6 (MOSI), J5.6
P22: J1.A2 (P22), J4.2
P23: J1.A4 (P23), J4.4
P24: J1.A6 (P24), J4.6
P25: J1.A8 (P25), J4.8
SCL: J1.B3 (SCL), J5.3, LIGHT.4 (SCL), PRESSURE.4 (SCL), R2.1, TEMP/HUMID.1 (SCK)
SCLK: J1.B10 (SCLK), J5.10
SDA: J1.B1 (SDA), J5.1, LIGHT.6 (SDA), PRESSURE.6 (SDA), R1.1, TEMP/HUMID.6 (SDA)
SWDCLK: J1.B2 (SWDCLK), J5.2
SWDIO/!RESET: J1.B4 (SWDIO/!RESET), J5.4
VCC: C1.1, C2.1, C3.1, C4.1, J1.A1 (VCC), J1.A3 (VCC), J4.1, J4.3, LIGHT.1 (VDD), PRESSURE.1 (VDD_IO), PRESSURE.8 (CS), PRESSURE.14 (VDD), PRESSURE.15 (VCCA), R1.2, R2.2, TEMP/HUMID.2 (VDD)

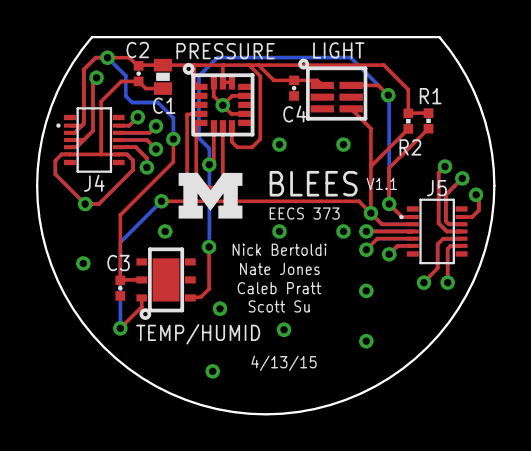
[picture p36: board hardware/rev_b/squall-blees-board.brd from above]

Board: 2 copper layers, 25.4 x 21.0 mm, 12 parts (0 on the bottom side), 17 nets.

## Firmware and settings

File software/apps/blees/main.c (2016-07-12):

/*
 * Advertises Sensor Data
 */

// Standard Libraries
#include <stdint.h>
#include <stdbool.h>
#include <stdio.h>
#include <string.h>
#include "math.h"

// Nordic Libraries
#include "app_util.h"
#include "app_error.h"
#include "app_gpiote.h"
#include "app_trace.h"
#include "app_scheduler.h"
#include "app_util_platform.h"
#include "app_timer.h"
#include "ble_conn_params.h"
#include "ble_hci.h"
#include "ble_hrs_c.h"
#include "ble_bas_c.h"
#include "ble_advdata.h"
#include "ble_gap.h"
#include "ble_gatts.h"
#include "ble_debug_assert_handler.h"
#include "ble.h"
#include "ble_db_discovery.h"
#include "ble_config.h"
#include "ble_ess.h"
#include "nordic_common.h"
#include "nrf.h"
#include "nrf_sdm.h"
#include "nrf_gpio.h"
#include "nrf_soc.h"
#include "nrf_drv_config.h"
#include "nrf_drv_gpiote.h"
#include "nrf_error.h"
#include "nrf_assert.h"
#include "nrf_drv_twi.h"
#include "pstorage.h"
#include "pstorage_platform.h"
#include "softdevice_handler.h"

// Platform, Peripherals, Devices, Services
#include "blees.h"
#include "simple_ble.h"
#include "simple_adv.h"
#include "multi_adv.h"
#include "eddystone.h"
#include "led.h"
#include "tsl2561.h"
#include "si7021.h"
#include "lps331ap.h"
#include "adxl362.h"
#include "spi_driver.h" // take this out eventually!

/*******************************************************************************
 *   DEFINES
 ******************************************************************************/

#define UMICH_COMPANY_IDENTIFIER      0x02E0
#define APP_BEACON_INFO_LENGTH        16
#define APP_BEACON_INFO_SERVICE_BLEES 0x12 // Registered to BLEES

#define ACCELEROMETER_INTERRUPT_PIN 5
#define LIGHT_INTERRUPT_PIN         22

/**< Value used as error code on stack dump, can be used to identify stack location on stack unwind. */
#define DEAD_BEEF                   0xDEADBEEF

#define UPDATE_RATE                 APP_TIMER_TICKS(1000, APP_TIMER_PRESCALER)

//Initial Pressure Parameters
#define INIT_PRES_DATA              456
#define PRES_TRIGGER_CONDITION      TRIG_FIXED_INTERVAL
#define PRES_TRIGGER_VAL_OPERAND    470
#define PRES_TRIGGER_VAL_TIME       APP_TIMER_TICKS(3000, APP_TIMER_PRESCALER)

//Initial Humidity Parameters
#define INIT_HUM_DATA               789
#define HUM_TRIGGER_CONDITION       TRIG_FIXED_INTERVAL
#define HUM_TRIGGER_VAL_OPERAND     799
#define HUM_TRIGGER_VAL_TIME        APP_TIMER_TICKS(3000, APP_TIMER_PRESCALER)

//Initial Temperature Parameters
#define INIT_TEMP_DATA              123
#define TEMP_TRIGGER_CONDITION      TRIG_FIXED_INTERVAL
#define TEMP_TRIGGER_VAL_OPERAND    156
#define TEMP_TRIGGER_VAL_TIME       APP_TIMER_TICKS(3000, APP_TIMER_PRESCALER)

//Initial Lux Parameters
#define INIT_LUX_DATA               789
#define LUX_TRIGGER_CONDITION       TRIG_FIXED_INTERVAL
#define LUX_TRIGGER_VAL_OPERAND     799
#define LUX_TRIGGER_VAL_TIME        APP_TIMER_TICKS(6000, APP_TIMER_PRESCALER)

//Initial Acceleration Parameters
#define INIT_ACC_DATA               789
#define ACC_TRIGGER_CONDITION       TRIG_FIXED_INTERVAL
#define ACC_TRIGGER_VAL_OPERAND     799
#define ACC_TRIGGER_VAL_TIME        APP_TIMER_TICKS(60000, APP_TIMER_PRESCALER)


// Maximum size is 17 characters, counting URLEND if used
// Demo App (using j2x and cdn.rawgit.com)
#define PHYSWEB_URL     "j2x.us/2ImXWJ"
#define ADV_SWITCH_MS 1000

/*******************************************************************************
 *   STATIC AND GLOBAL VARIABLES
 ******************************************************************************/

uint8_t MAC_ADDR[6] = {0x00, 0x00, 0x30, 0xe5, 0x98, 0xc0};
nrf_drv_twi_t twi_instance = NRF_DRV_TWI_INSTANCE(1);

static ble_uuid_t ESS_SERVICE_UUID[] = {{ESS_UUID_SERVICE, BLE_UUID_TYPE_BLE}};

static ble_ess_t                    m_ess;
static uint8_t                      m_beacon_info[APP_BEACON_INFO_LENGTH];

APP_TIMER_DEF(m_pres_timer_id);     /**< ESS Pressure timer. */
APP_TIMER_DEF(m_hum_timer_id);      /**< ESS Humidity timer. */
APP_TIMER_DEF(m_temp_timer_id);     /**< ESS Temperature timer. */
APP_TIMER_DEF(m_lux_timer_id);      /**< ESS Lux timer. */
APP_TIMER_DEF(m_acc_timer_id);      /**< ESS Accelerometer timer. */

// Need this for the app_gpiote library
app_gpiote_user_id_t gpiote_user_acc;
app_gpiote_user_id_t gpiote_user_light;

static bool data_updated = false;

static struct {
    uint32_t pressure;
    uint16_t humidity;
    int16_t temp;
    uint16_t light;
    uint8_t acceleration;
    uint32_t sequence_num;
} m_sensor_info = {1.0f, 2.0f, 3.0f, 4.0f, 0.0f, 0};

// Intervals for advertising and connections
static simple_ble_config_t ble_config = {
    .platform_id       = 0x30,              // used as 4th octect in device BLE address
    .device_id         = DEVICE_ID_DEFAULT,
    .adv_name          = DEVICE_NAME,       // used in advertisements if there is room
    .adv_interval      = APP_ADV_INTERVAL,
    .min_conn_interval = MIN_CONN_INTERVAL,
    .max_conn_interval = MAX_CONN_INTERVAL,
};

/*******************************************************************************
 *   FUNCTION PROTOTYPES
 ******************************************************************************/
static void update_timers( ble_evt_t * p_ble_evt );

/*******************************************************************************
 *   HANDLERS AND CALLBACKS
 ******************************************************************************/

void ble_error(uint32_t error_code) {
    led_init(SQUALL_LED_PIN);
    led_on(SQUALL_LED_PIN);
    while(1);
}

void ble_evt_write(ble_evt_t* p_ble_evt) {
    update_timers(p_ble_evt);
}

void ble_evt_user_handler (ble_evt_t* p_ble_evt) {
    ble_ess_on_ble_evt(&m_ess, p_ble_evt);
}

static void acc_interrupt_handler (uint32_t pins_l2h, uint32_t pins_h2l) {
    if (pins_h2l & (1 << ACCELEROMETER_INTERRUPT_PIN)) {
        // High to low transition
        led_on(BLEES_LED_PIN);

        m_sensor_info.acceleration = 0x11;

        for (volatile int i = 0; i < 1000; i++);
        led_off(BLEES_LED_PIN);

        // stop timer if running
        app_timer_stop(m_acc_timer_id);

    } else if (pins_l2h & (1 << ACCELEROMETER_INTERRUPT_PIN)) {
        // Low to high transition
        m_sensor_info.acceleration = 0x01;

        // Call a one-shot timer here to set accel to low if it ever fires
        app_timer_start(m_acc_timer_id, (uint32_t) ACC_TRIGGER_VAL_TIME, NULL);
    }

    data_updated = true;
}

static void light_interrupt_handler (uint32_t pins_l2h, uint32_t pins_h2l) {
    if (pins_h2l & (1 << LIGHT_INTERRUPT_PIN)) {
        // High to low transition

        // Need to re-enable I2C to get reading from sensor
        nrf_drv_twi_enable(&twi_instance);
        // Get the lux value from the stored registers on the chip
        uint16_t lux = (uint16_t)tsl2561_read_lux();

        // Now turn the sensor back off and put it in low power mode
        tsl2561_off();
        // Stop I2C
        nrf_drv_twi_disable(&twi_instance);

        // Update our global state and update our advertisement.
        m_sensor_info.light = lux;
        data_updated = true;
/*
        //XXX: what is going on here?
        uint8_t lux_meas_val[2];
        memcpy(lux_meas_val, &lux, 2);

        // Update the service characteristic as well.
        uint32_t err_code = ble_ess_char_value_update(&m_ess, &(m_ess.lux), lux_meas_val,
                MAX_LUX_LEN, false, &(m_ess.lux_char_handles) );

        if ((err_code != NRF_SUCCESS) &&
            (err_code != NRF_ERROR_INVALID_STATE) &&
            (err_code != BLE_ERROR_NO_TX_BUFFERS) &&
            (err_code != BLE_ERROR_GATTS_SYS_ATTR_MISSING)) {

            APP_ERROR_HANDLER(err_code);
        }
*/
    }
}


static void gpio_init (void) {
    // Need two users: accelerometer and light
    APP_GPIOTE_INIT(2);

    // Register the accelerometer
    app_gpiote_user_register(&gpiote_user_acc,
            1<<ACCELEROMETER_INTERRUPT_PIN,   // Which pins we want the interrupt for low to high
            1<<ACCELEROMETER_INTERRUPT_PIN,   // Which pins we want the interrupt for high to low
            acc_interrupt_handler);

    // Register the light sensor interrupt
    uint32_t err = app_gpiote_user_register(&gpiote_user_light,
            0,                        // Which pins we want the interrupt for low to high
            1<<LIGHT_INTERRUPT_PIN,   // Which pins we want the interrupt for high to low
            light_interrupt_handler);
    APP_ERROR_CHECK(err);


    // Light sensor interrupt pin needs a pull up resistor
    nrf_gpio_cfg_input(LIGHT_INTERRUPT_PIN, NRF_GPIO_PIN_PULLUP);

    // Enable the interrupts!
    app_gpiote_user_enable(gpiote_user_acc);
    app_gpiote_user_enable(gpiote_user_light);
}

static void pres_take_measurement(void * p_context) {

    //lps331ap_power_on();

    UNUSED_PARAMETER(p_context);

    uint8_t  pres_meas_val[4];

    uint32_t meas;
    memset(&meas, 0, sizeof(meas));

    float pres;
    memset(&pres, 0, sizeof(pres));

    nrf_drv_twi_enable(&twi_instance);

    lps331ap_one_shot_enable();

    lps331ap_readPressure(&pres);

    //lps331ap_power_off();

    nrf_drv_twi_disable(&twi_instance);

    meas = (uint32_t)(pres * 1000);
    m_sensor_info.pressure = meas;
    data_updated = true;

    memcpy(pres_meas_val, &meas, 4);

    uint32_t err_code = ble_ess_char_value_update(&m_ess, &(m_ess.pressure), pres_meas_val,
            MAX_PRES_LEN, false, &(m_ess.pres_char_handles) );

    if ((err_code != NRF_SUCCESS) &&
        (err_code != NRF_ERROR_INVALID_STATE) &&
        (err_code != BLE_ERROR_NO_TX_BUFFERS) &&
        (err_code != BLE_ERROR_GATTS_SYS_ATTR_MISSING)) {

        APP_ERROR_HANDLER(err_code);
    }
}

static void hum_take_measurement(void * p_context) {
    UNUSED_PARAMETER(p_context);

    uint8_t  hum_meas_val[2];

    uint32_t meas;
    memset(&meas, 0, sizeof(meas));

    float hum;
    memset(&hum, 0, sizeof(hum));

    nrf_drv_twi_enable(&twi_instance);

    (si7021_read_RH(&hum));

    nrf_drv_twi_disable(&twi_instance);

    meas = (uint16_t)(hum * 100);
    m_sensor_info.humidity = meas;
    data_updated = true;

    memcpy(hum_meas_val, &meas, 2);

    uint32_t err_code = ble_ess_char_value_update(&m_ess, &(m_ess.humidity), hum_meas_val,
            MAX_HUM_LEN, false, &(m_ess.hum_char_handles) );

    if ((err_code != NRF_SUCCESS) &&
        (err_code != NRF_ERROR_INVALID_STATE) &&
        (err_code != BLE_ERROR_NO_TX_BUFFERS) &&
        (err_code != BLE_ERROR_GATTS_SYS_ATTR_MISSING)) {

        APP_ERROR_HANDLER(err_code);
    }
}

static void temp_take_measurement(void * p_context) {
    UNUSED_PARAMETER(p_context);

    uint8_t  temp_meas_val[2];

    uint32_t meas;
    memset(&meas, 0, sizeof(meas));

    float temp;
    memset(&temp, 0, sizeof(temp));

    nrf_drv_twi_enable(&twi_instance);

    si7021_read_temp(&temp);

    nrf_drv_twi_disable(&twi_instance);

    meas = (int16_t)(temp * 100);
    m_sensor_info.temp = meas;
    data_updated = true;

    memcpy(temp_meas_val, &meas, 2);

    uint32_t err_code = ble_ess_char_value_update(&m_ess, &(m_ess.temperature), temp_meas_val,
            MAX_TEMP_LEN, false, &(m_ess.temp_char_handles) );

    if ((err_code != NRF_SUCCESS) &&
        (err_code != NRF_ERROR_INVALID_STATE) &&
        (err_code != BLE_ERROR_NO_TX_BUFFERS) &&
        (err_code != BLE_ERROR_GATTS_SYS_ATTR_MISSING)) {

        APP_ERROR_HANDLER(err_code);
    }
}

static void lux_take_measurement(void * p_context) {
    UNUSED_PARAMETER(p_context);
    nrf_drv_twi_enable(&twi_instance);
    tsl2561_on();
    tsl2561_config(tsl2561_GAIN_LOW, tsl2561_INTEGRATION_101MS);
    tsl2561_interrupt_enable();
    nrf_drv_twi_disable(&twi_instance);
}

static void acc_timeout_handler(void* p_context) {
    UNUSED_PARAMETER(p_context);

    m_sensor_info.acceleration = 0x00;
    data_updated = true;

    ble_ess_char_value_update(&m_ess, &(m_ess.acceleration), &(m_sensor_info.acceleration),
            MAX_ACC_LEN, false, &(m_ess.acc_char_handles));
}

/*******************************************************************************
 *   INIT FUNCTIONS
 ******************************************************************************/

static void timers_init(void) {
    uint32_t err_code;

    // Initialize timer for Pressure Trigger
    err_code = app_timer_create(&m_pres_timer_id,
            APP_TIMER_MODE_REPEATED,
            pres_take_measurement);
    APP_ERROR_CHECK(err_code);

    // Initialize timer for Humidity Trigger
    err_code = app_timer_create(&m_hum_timer_id,
            APP_TIMER_MODE_REPEATED,
            hum_take_measurement);
    APP_ERROR_CHECK(err_code);

    // Initialize timer for Temperature trigger
    err_code = app_timer_create(&m_temp_timer_id,
            APP_TIMER_MODE_REPEATED,
            temp_take_measurement);
    APP_ERROR_CHECK(err_code);

    // Initialize timer for Lux Trigger
    err_code = app_timer_create(&m_lux_timer_id,
            APP_TIMER_MODE_REPEATED,
            lux_take_measurement);
    APP_ERROR_CHECK(err_code);

    // Initialize timer for Acc Trigger
    err_code = app_timer_create(&m_acc_timer_id,
            APP_TIMER_MODE_SINGLE_SHOT,
            acc_timeout_handler);
    APP_ERROR_CHECK(err_code);
}

/**@brief Function for initializing the pressure.*/
static void pres_char_init(ble_ess_init_t * p_ess_init) {
    p_ess_init->pres_trigger_data.condition = PRES_TRIGGER_CONDITION;
    p_ess_init->init_pres_data = (uint32_t)(INIT_PRES_DATA);
    p_ess_init->pres_trigger_val_var = (uint32_t)(PRES_TRIGGER_VAL_OPERAND);
    p_ess_init->pres_trigger_data.time_interval = (uint32_t)(PRES_TRIGGER_VAL_TIME);
}

/**@brief Function for initializing the humidity.*/
static void hum_char_init(ble_ess_init_t * p_ess_init) {
    p_ess_init->hum_trigger_data.condition = HUM_TRIGGER_CONDITION;
    p_ess_init->init_hum_data = (uint16_t)(INIT_HUM_DATA);
    p_ess_init->hum_trigger_val_var = (uint16_t)(HUM_TRIGGER_VAL_OPERAND);
    p_ess_init->hum_trigger_data.time_interval = (uint32_t)(HUM_TRIGGER_VAL_TIME);
}

/**@brief Function for initializing the temperature.*/
static void temp_char_init(ble_ess_init_t * p_ess_init) {
    p_ess_init->temp_trigger_data.condition = TEMP_TRIGGER_CONDITION;
    p_ess_init->init_temp_data = (int16_t)(INIT_TEMP_DATA);
    p_ess_init->temp_trigger_val_var = (int16_t)(TEMP_TRIGGER_VAL_OPERAND);
    p_ess_init->temp_trigger_data.time_interval = (uint32_t)(TEMP_TRIGGER_VAL_TIME);
}

/**@brief Function for initializing lux.*/
static void lux_char_init(ble_ess_init_t * p_ess_init) {
    p_ess_init->lux_trigger_data.condition = LUX_TRIGGER_CONDITION;
    p_ess_init->init_lux_data = (uint16_t)(INIT_LUX_DATA);
    p_ess_init->lux_trigger_val_var = (uint16_t)(LUX_TRIGGER_VAL_OPERAND);
    p_ess_init->lux_trigger_data.time_interval = (uint32_t)(LUX_TRIGGER_VAL_TIME);
}

/**@brief Function for initializing the acceleration.*/
static void acc_char_init(ble_ess_init_t * p_ess_init) {
    p_ess_init->acc_trigger_data.condition = ACC_TRIGGER_CONDITION;
    p_ess_init->init_acc_data = (uint8_t)(INIT_ACC_DATA);
    p_ess_init->acc_trigger_val_var = (uint16_t)(ACC_TRIGGER_VAL_OPERAND);
    p_ess_init->acc_trigger_data.time_interval = (uint32_t)(ACC_TRIGGER_VAL_TIME);
}


/**@brief Function for initializing the sensor simulators.*/
static void sensors_init(void) {

    nrf_drv_twi_config_t twi_config;

    // Initialize the I2C module
    twi_config.sda                = I2C_SDA_PIN;
    twi_config.scl                = I2C_SCL_PIN;
    twi_config.frequency          = NRF_TWI_FREQ_400K;
    twi_config.interrupt_priority = APP_IRQ_PRIORITY_HIGH;

    nrf_drv_twi_init(&twi_instance, &twi_config, NULL, NULL);
    nrf_drv_twi_enable(&twi_instance);

    //initialize pressure
    lps331ap_init(&twi_instance);
    lps331ap_sw_reset();
    lps331ap_sw_reset_disable();
    lps331ap_power_off();
    lps331ap_config(lps331ap_MODE1, lps331ap_P_RES_10, lps331ap_T_RES_7);
    lps331ap_one_shot_config();
    lps331ap_amp_control(true);
    lps331ap_power_on();
    //lps331ap_power_off();

    //initialize humidity and temperature
    si7021_init(&twi_instance);
    si7021_reset();
    si7021_heater_off();

    //initialize lux
    tsl2561_driver_init(&twi_instance, 0b00101001);

    //initialize accelerometer
    adxl362_accelerometer_init(adxl362_NOISE_NORMAL, true, false, false);
    uint16_t act_thresh = 0x0070;
    adxl362_set_activity_threshold(act_thresh);
    uint16_t inact_thresh = 0x0096;
    adxl362_set_inactivity_threshold(inact_thresh);
    uint8_t a_time = 4;
    adxl362_set_activity_time(a_time);
    uint8_t ia_time = 30;
    adxl362_set_inactivity_time(ia_time);

    adxl362_interrupt_map_t intmap_2;

    //adxl362_interrupt_map_t intmap_1, intmap_2;
    /*
    intmap_1.DATA_READY = 0;
    intmap_1.FIFO_READY = 0;
    intmap_1.FIFO_WATERMARK = 0;
    intmap_1.FIFO_OVERRUN = 0;
    intmap_1.ACT = 1;
    intmap_1.INACT = 0;
    intmap_1.AWAKE = 0;
    intmap_1.INT_LOW = 1;
    adxl362_config_INTMAP(&intmap_1, true);
    */

    intmap_2.DATA_READY = 0;
    intmap_2.FIFO_READY = 0;
    intmap_2.FIFO_WATERMARK = 0;
    intmap_2.FIFO_OVERRUN = 0;
    intmap_2.ACT = 0;
    intmap_2.INACT = 0;
    intmap_2.AWAKE = 1;
    intmap_2.INT_LOW = 1;
    adxl362_config_INTMAP(&intmap_2, false);

    adxl362_config_interrupt_mode(adxl362_INTERRUPT_LOOP, true , true);
    adxl362_activity_inactivity_interrupt_enable();

    adxl362_read_status_reg();

    spi_disable();
    nrf_drv_twi_disable(&twi_instance);


}

static void on_ess_evt (ble_ess_t * p_ess, ble_ess_evt_t * p_evt) {
    // Nothing to do for now
}

// init services
void services_init (void) {

    uint32_t err_code;

    ble_ess_init_t ess_init;
    memset(&ess_init, 0 , sizeof(ess_init));

    ess_init.evt_handler = on_ess_evt;
    ess_init.is_notify_supported = true;

    pres_char_init(&ess_init);  //initialize pres
    hum_char_init(&ess_init);   //initialize hum
    temp_char_init(&ess_init);  //initialize temp
    lux_char_init(&ess_init);   //initialize lux
    acc_char_init(&ess_init);   //initialize acc

    err_code = ble_ess_init(&m_ess, &ess_init);
    APP_ERROR_CHECK(err_code);
}

void dfu_reset_prepare (void) {

    // Disable the interrupts!
    app_gpiote_user_disable(gpiote_user_acc);
    app_gpiote_user_disable(gpiote_user_light);

    // reset accelerometer
    spi_enable();
    adxl362_accelerometer_reset();
    spi_disable();

    // disable pressure
    lps331ap_power_off();

    // disable lux
    tsl2561_off();

    // disable i2c
    nrf_drv_twi_disable(&twi_instance);
}

/*******************************************************************************
 *   HELPER FUNCTIONS
 ******************************************************************************/

static void timers_start(void) {
    uint32_t err_code;

    err_code = app_timer_start(m_pres_timer_id, (uint32_t) PRES_TRIGGER_VAL_TIME, NULL);
    APP_ERROR_CHECK(err_code);

    err_code = app_timer_start(m_hum_timer_id, (uint32_t) HUM_TRIGGER_VAL_TIME, NULL);
    APP_ERROR_CHECK(err_code);

    err_code = app_timer_start(m_temp_timer_id, (uint32_t) TEMP_TRIGGER_VAL_TIME, NULL);
    APP_ERROR_CHECK(err_code);

    err_code = app_timer_start(m_lux_timer_id, (uint32_t) LUX_TRIGGER_VAL_TIME, NULL);
    APP_ERROR_CHECK(err_code);
}
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
int main(void) {

    // Setup BLE
    simple_ble_init(&ble_config);
    timers_init();
    gpio_init();
    led_init(BLEES_LED_PIN);

    // enable internal DC-DC converter to save power
    // BANISH THIS EVIL LINE
    // sd_power_dcdc_mode_set(NRF_POWER_DCDC_ENABLE);

    // Need to init multi adv
    multi_adv_init(ADV_SWITCH_MS);

    // Now register our advertisement configure functions
    multi_adv_register_config(adv_config_eddystone);
    multi_adv_register_config(adv_config_data);

    // setup the sensor configurations
    sensors_init();

    // Start execution
    timers_start();

    // Start rotating the advertisements.
    multi_adv_start();

    while (1) {
        power_manage();
    }
}

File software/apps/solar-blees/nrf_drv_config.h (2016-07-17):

/* Copyright (c) 2015 Nordic Semiconductor. All Rights Reserved.
 *
 * The information contained herein is property of Nordic Semiconductor ASA.
 * Terms and conditions of usage are described in detail in NORDIC
 * SEMICONDUCTOR STANDARD SOFTWARE LICENSE AGREEMENT.
 *
 * Licensees are granted free, non-transferable use of the information. NO
 * WARRANTY of ANY KIND is provided. This heading must NOT be removed from
 * the file.
 *
 */

#ifndef NRF_DRV_CONFIG_H
#define NRF_DRV_CONFIG_H

/**
 * Provide a non-zero value here in applications that need to use several
 * peripherals with the same ID that are sharing certain resources
 * (for example, SPI0 and TWI0). Obviously, such peripherals cannot be used
 * simultaneously. Therefore, this definition allows to initialize the driver
 * for another peripheral from a given group only after the previously used one
 * is uninitialized. Normally, this is not possible, because interrupt handlers
 * are implemented in individual drivers.
 * This functionality requires a more complicated interrupt handling and driver
 * initialization, hence it is not always desirable to use it.
 */
#define PERIPHERAL_RESOURCE_SHARING_ENABLED  0

/* CLOCK */
#define CLOCK_ENABLED 0

#if (CLOCK_ENABLED == 1)
#define CLOCK_CONFIG_XTAL_FREQ          NRF_CLOCK_XTALFREQ_Default
#define CLOCK_CONFIG_LF_SRC             NRF_CLOCK_LF_SRC_Xtal
#define CLOCK_CONFIG_IRQ_PRIORITY       APP_IRQ_PRIORITY_LOW
#endif

/* GPIOTE */
#define GPIOTE_ENABLED 1

#if (GPIOTE_ENABLED == 1)
#define GPIOTE_CONFIG_USE_SWI_EGU false
#define GPIOTE_CONFIG_IRQ_PRIORITY APP_IRQ_PRIORITY_LOW
#define GPIOTE_CONFIG_NUM_OF_LOW_POWER_EVENTS 1
#endif

/* TIMER */
#define TIMER0_ENABLED 0

#if (TIMER0_ENABLED == 1)
#define TIMER0_CONFIG_FREQUENCY    NRF_TIMER_FREQ_16MHz
#define TIMER0_CONFIG_MODE         TIMER_MODE_MODE_Timer
#define TIMER0_CONFIG_BIT_WIDTH    TIMER_BITMODE_BITMODE_32Bit
#define TIMER0_CONFIG_IRQ_PRIORITY APP_IRQ_PRIORITY_LOW

#define TIMER0_INSTANCE_INDEX      0
#endif

#define TIMER1_ENABLED 0

#if (TIMER1_ENABLED == 1)
#define TIMER1_CONFIG_FREQUENCY    NRF_TIMER_FREQ_16MHz
#define TIMER1_CONFIG_MODE         TIMER_MODE_MODE_Timer
#define TIMER1_CONFIG_BIT_WIDTH    TIMER_BITMODE_BITMODE_16Bit
#define TIMER1_CONFIG_IRQ_PRIORITY APP_IRQ_PRIORITY_LOW

#define TIMER1_INSTANCE_INDEX      (TIMER0_ENABLED)
#endif

#define TIMER2_ENABLED 0

#if (TIMER2_ENABLED == 1)
#define TIMER2_CONFIG_FREQUENCY    NRF_TIMER_FREQ_16MHz
#define TIMER2_CONFIG_MODE         TIMER_MODE_MODE_Timer
#define TIMER2_CONFIG_BIT_WIDTH    TIMER_BITMODE_BITMODE_16Bit
#define TIMER2_CONFIG_IRQ_PRIORITY APP_IRQ_PRIORITY_LOW

#define TIMER2_INSTANCE_INDEX      (TIMER1_ENABLED+TIMER0_ENABLED)
#endif

#define TIMER3_ENABLED 0

#if (TIMER3_ENABLED == 1)
#define TIMER3_CONFIG_FREQUENCY    NRF_TIMER_FREQ_16MHz
#define TIMER3_CONFIG_MODE         TIMER_MODE_MODE_Timer
#define TIMER3_CONFIG_BIT_WIDTH    TIMER_BITMODE_BITMODE_16Bit
#define TIMER3_CONFIG_IRQ_PRIORITY APP_IRQ_PRIORITY_LOW

#define TIMER3_INSTANCE_INDEX      (TIMER2_ENABLED+TIMER1_ENABLED+TIMER0_ENABLED)
#endif

#define TIMER4_ENABLED 0

#if (TIMER4_ENABLED == 1)
#define TIMER4_CONFIG_FREQUENCY    NRF_TIMER_FREQ_16MHz
#define TIMER4_CONFIG_MODE         TIMER_MODE_MODE_Timer
#define TIMER4_CONFIG_BIT_WIDTH    TIMER_BITMODE_BITMODE_16Bit
#define TIMER4_CONFIG_IRQ_PRIORITY APP_IRQ_PRIORITY_LOW

#define TIMER4_INSTANCE_INDEX      (TIMER3_ENABLED+TIMER2_ENABLED+TIMER1_ENABLED+TIMER0_ENABLED)
#endif


#define TIMER_COUNT (TIMER0_ENABLED + TIMER1_ENABLED + TIMER2_ENABLED + TIMER3_ENABLED + TIMER4_ENABLED)

/* RTC */
#define RTC0_ENABLED 0

#if (RTC0_ENABLED == 1)
#define RTC0_CONFIG_FREQUENCY    32678
#define RTC0_CONFIG_IRQ_PRIORITY APP_IRQ_PRIORITY_LOW
#define RTC0_CONFIG_RELIABLE     false

#define RTC0_INSTANCE_INDEX      0
#endif

#define RTC1_ENABLED 0

#if (RTC1_ENABLED == 1)
#define RTC1_CONFIG_FREQUENCY    32768
#define RTC1_CONFIG_IRQ_PRIORITY APP_IRQ_PRIORITY_LOW
#define RTC1_CONFIG_RELIABLE     false

#define RTC1_INSTANCE_INDEX      (RTC0_ENABLED)
#endif

#define RTC_COUNT                (RTC0_ENABLED+RTC1_ENABLED)

#define NRF_MAXIMUM_LATENCY_US 2000

/* RNG */
#define RNG_ENABLED 0

#if (RNG_ENABLED == 1)
#define RNG_CONFIG_ERROR_CORRECTION true
#define RNG_CONFIG_POOL_SIZE        8
#define RNG_CONFIG_IRQ_PRIORITY     APP_IRQ_PRIORITY_LOW
#endif

/* PWM */

#define PWM0_ENABLED 0

#if (PWM0_ENABLED == 1)
#define PWM0_CONFIG_OUT0_PIN        2
#define PWM0_CONFIG_OUT1_PIN        3
#define PWM0_CONFIG_OUT2_PIN        4
#define PWM0_CONFIG_OUT3_PIN        5
#define PWM0_CONFIG_IRQ_PRIORITY    APP_IRQ_PRIORITY_LOW
#define PWM0_CONFIG_BASE_CLOCK      NRF_PWM_CLK_1MHz
#define PWM0_CONFIG_COUNT_MODE      NRF_PWM_MODE_UP
#define PWM0_CONFIG_TOP_VALUE       1000
#define PWM0_CONFIG_LOAD_MODE       NRF_PWM_LOAD_COMMON
#define PWM0_CONFIG_STEP_MODE       NRF_PWM_STEP_AUTO

#define PWM0_INSTANCE_INDEX 0
#endif

#define PWM1_ENABLED 0
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

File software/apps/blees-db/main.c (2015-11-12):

/*
 * Advertises Sensor Data
 */

// Standard Libraries
#include <stdint.h>
#include <stdbool.h>
#include <stdio.h>
#include <string.h>
#include "math.h"

// Nordic Libraries
#include "app_util.h"
#include "app_error.h"
#include "app_trace.h"
#include "app_scheduler.h"
#include "app_util_platform.h"
#include "app_timer.h"
#include "ble_advdata_parser.h"
#include "ble_conn_params.h"
#include "ble_hci.h"
#include "ble_hrs_c.h"
#include "ble_bas_c.h"
#include "ble_advdata.h"
#include "ble_gap.h"
#include "ble_gatts.h"
#include "ble_debug_assert_handler.h"
#include "ble.h"
#include "ble_db_discovery.h"
#include "ble_config.h"
#include "ble_ess.h"
#include "nordic_common.h"
#include "nrf.h"
#include "nrf_sdm.h"
#include "nrf_gpio.h"
#include "nrf_soc.h"
#include "nrf_gpiote.h"
#include "nrf_drv_config.h"
#include "nrf_drv_gpiote.h"
#include "nrf_error.h"
#include "nrf_assert.h"
#include "nrf_drv_twi.h"
#include "pstorage.h"
#include "pstorage_platform.h"
#include "softdevice_handler.h"

// Platform, Peripherals, Devices, Services
#include "blees.h"
#include "led.h"
#include "tsl2561.h"
#include "si7021.h"
#include "lps331ap.h"
#include "adxl362.h"
#include "spi_driver.h" // take this out eventually!

 #include "dbparser.h"

/*******************************************************************************
 *   DEFINES
 ******************************************************************************/

#define APP_BEACON_INFO_LENGTH      11

#define PIN_IN                      5

#define APP_GPIOTE_MAX_USERS        1                                              /**< Maximum number of users of the GPIOTE handler. */

#define DEAD_BEEF                   0xDEADBEEF                                     /**< Value used as error code on stack dump, can be used to identify stack location on stack unwind. */

#define UPDATE_RATE                 APP_TIMER_TICKS(1000, APP_TIMER_PRESCALER)

//Initial Pressure Parameters
#define INIT_PRES_DATA              456
#define PRES_TRIGGER_CONDITION      TRIG_FIXED_INTERVAL
#define PRES_TRIGGER_VAL_OPERAND    470
#define PRES_TRIGGER_VAL_TIME       APP_TIMER_TICKS(3000, APP_TIMER_PRESCALER)

//Initial Humidity Parameters
#define INIT_HUM_DATA               789
#define HUM_TRIGGER_CONDITION       TRIG_FIXED_INTERVAL
#define HUM_TRIGGER_VAL_OPERAND     799
#define HUM_TRIGGER_VAL_TIME        APP_TIMER_TICKS(3000, APP_TIMER_PRESCALER)

//Initial Temperature Parameters
#define INIT_TEMP_DATA              123
#define TEMP_TRIGGER_CONDITION      TRIG_FIXED_INTERVAL
#define TEMP_TRIGGER_VAL_OPERAND    156
#define TEMP_TRIGGER_VAL_TIME       APP_TIMER_TICKS(3000, APP_TIMER_PRESCALER)

//Initial Lux Parameters
#define INIT_LUX_DATA               789
#define LUX_TRIGGER_CONDITION       TRIG_FIXED_INTERVAL
#define LUX_TRIGGER_VAL_OPERAND     799
#define LUX_TRIGGER_VAL_TIME        APP_TIMER_TICKS(6000, APP_TIMER_PRESCALER)

//Initial Acceleration Parameters
#define INIT_ACC_DATA               789
#define ACC_TRIGGER_CONDITION       TRIG_FIXED_INTERVAL
#define ACC_TRIGGER_VAL_OPERAND     799
#define ACC_TRIGGER_VAL_TIME        APP_TIMER_TICKS(3000, APP_TIMER_PRESCALER)


// Maximum size is 17 characters, counting URLEND if used
// Main App
//#define PHYSWEB_URL     "goo.gl/tM8s2Y"
// Demo App (http://nuclear.eecs.umich.edu/public/ble/blees-demo/index.html)
#define PHYSWEB_URL     "goo.gl/xWppj1"

/*******************************************************************************
 *   STATIC AND GLOBAL VARIABLES
 ******************************************************************************/

uint8_t MAC_ADDR[6] = {0x00, 0x00, 0x30, 0xe5, 0x98, 0xc0};
nrf_drv_twi_t twi_instance = NRF_DRV_TWI_INSTANCE(1);

static ble_app_t                    app;
static ble_gap_adv_params_t         m_adv_params;
static ble_advdata_t                advdata;
static ble_ess_t                    m_ess;
static uint8_t                      m_beacon_info[APP_BEACON_INFO_LENGTH];
static uint16_t                     m_conn_handle = BLE_CONN_HANDLE_INVALID;     /**< Handle of the current connection. */

static app_timer_id_t               sample_timer;                                /**< Advertisement timer. */
static app_timer_id_t               m_pres_timer_id;                             /**< ESS Pressure timer. */
static app_timer_id_t               m_hum_timer_id;                              /**< ESS Humidity timer. */
static app_timer_id_t               m_temp_timer_id;                             /**< ESS Temperature timer. */
static app_timer_id_t               m_lux_timer_id;                              /**< ESS Lux timer. */
static app_timer_id_t               m_lux_wait_timer_id;                              /**< ESS Lux timer. */

static app_timer_id_t               m_acc_timer_id;                              /**< ESS Accelerometer timer. */

static bool                         m_ess_updating_advdata = false;
static bool                         switch_acc = false;

static bool PHYSWEB_MODE = false;

// DB Variables
#define DB_WORKING_MEM_SIZE 2000
uint8_t db_memory[DB_WORKING_MEM_SIZE];

// Security requirements for this application.
static ble_gap_sec_params_t m_sec_params =
{
    SEC_PARAM_BOND,
    SEC_PARAM_MITM,
    SEC_PARAM_IO_CAPABILITIES,
    SEC_PARAM_OOB,
    SEC_PARAM_MIN_KEY_SIZE,
    SEC_PARAM_MAX_KEY_SIZE,
};

static struct {
    uint32_t pressure;
    uint16_t humidity;
    int16_t temp;
    uint16_t light;
    uint8_t acceleration;
} m_sensor_info = {1.0f, 2.0f, 3.0f, 4.0f, 0.0f};

/*******************************************************************************
 *   FUNCTION PROTOTYPES
 ******************************************************************************/
static void advertising_start(void);
static void advertising_stop(void);
static bool update_advdata(void);
static void update_timers( ble_evt_t * p_ble_evt );
static void adv_physweb(void);

/*******************************************************************************
 *   HANDLERS AND CALLBACKS
 ******************************************************************************/
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

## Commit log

2015-03-17 Add EAGLE layout base for hardware
    [squall-blees-board.brd, squall-blees-board.sch]
2015-03-23 Finish basic android app, add pressure data to squall
2015-03-26 Start working on communicating with sensors
2015-03-27 comment out I2C stuff
2015-03-27 Added timer interrupts
2015-03-27 Getting Pressure(maybe) data
2015-03-27 Read from [x] Pressure; [ ] Temp/Hum; [ ] Lux
2015-03-31 All sensors now communicating. Light sensor is very funky though, and only sometimes works. Note that the light sensor is only working due to a hack and the fact that the TWI library seems to be bugg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
    [main.c]
2015-04-01 Add a couple components we use, and add Lab11s components that we will use
2015-04-01 Use SW TWI control instead of HW TWI control, this fixes the bug when communicating with the light sensor
    [main.c]
2015-04-02 Work on circuit board
    [squall-blees-board.brd, squall-blees-board.sch]
2015-04-03 Board finished
    [squall-blees-board.brd, squall-blees-board.sch]
2015-04-06 Board ready for prod
    [squall-blees-board.brd, squall-blees-board.sch]
2015-04-06 Make changes to text, output gerbers, panelize
    [merge.cfg, squall-blees-board.brd, squall-blees-board.sch]
2015-04-07 New panelized boards
    [merge.cfg, squall-blees-board.brd, squall-blees-board.sch]
2015-04-07 Fix drill output, need to export with EXCELLON_24 for one reason or another
    [merge.cfg]
2015-04-07 Remove borders from panelized boards, and move panelized outlines to different layers in the original board. Use CAM processor to get the different outlines
    [merge.cfg, squall-blees-board.brd, squall-blees-board.sch]
2015-04-07 Gerber zip files
2015-04-09 Send sensor data as floats
2015-04-14 Add Rev B to fix temperature/humidity sensor connections
    [squall-blees-board.brd, squall-blees-board.sch]
2015-04-14 Update rev_b, send it for fabrication
    [merge.cfg, squall-blees-board.brd, squall-blees-board.sch]
2015-04-17 4 sig digits for pressure
2015-04-19 Fix bug with multiple BLEES devices
2015-04-19 Power saving added
2015-04-19 Turns off sensors that don't need to be always on
2015-04-24 Add BOM for Rev_B
    [BLEES_REVB_BOM.csv]
2015-06-09 First pass at rev C BLEES
    Includes a MPU-9250 9DOF as well as connected interrupt lines
    [squall-blees-board.brd, squall-blees-board.sch]
2015-06-12 Second pass at Rev C of BLEES. Added accelerometer
    [squall-blees-board.brd, squall-blees-board.sch]
2015-06-12 Panelized version of rev C BLEES
    [merge.cfg, revC_frame.brd, squall-blees-board.brd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]
2015-06-13 Swapped out temp/humidity sensor
    This one is lower power, same functionality, and purchasable
    [squall-blees-board.brd, squall-blees-board.sch, squall-blees-board_bom.csv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]
2015-06-19 Main works with LED and populated sensors
2015-07-12 SPI successfully functions
2015-07-12 Revisions to BOM for assembler
    [squall-blees-board_bom.xlsx]
2015-07-12 Actually displays X-Axis data. Overwrites pressure
2015-07-22 Pressure sensor displays data
2015-07-22 Added solder paste gerber files
    [merge.cfg]
2015-07-24 added light sensor drivers
2015-07-28 Working on sensor drivers...
2015-07-30 Still fixing drivers...
2015-07-30 Fixed pressure sensor to work w/ sdk9 and updated gitignore
2015-07-31 Fixed for new SDK, accelerator data kinda working
    [adxl362.c, tsl2561.c]
2015-07-31 Trying to make light sensor interrupt work
2015-08-04 Interrupts work, Modes work, working on FIFO
2015-08-05 Code to swap between real-time data and phys-web
    [main.c, nrf_drv_config.h]
2015-08-05 Acc interrupts working, working on light sensor one shot
2015-08-12 Continuous advertisements of correct data, can connect for temp, pres, hum
    [main.c]
2015-08-12 Currently updates advdata and ess_data separately... will fix this
    [main.c]
2015-08-17 Acc interrupt working!!!!
2015-08-18 Fixed minor timing issue Working??
    [main.c]
2015-08-24 Icons for acceleration, humidity, pressure
2015-08-26 Changed led interval, can write more to pressure
2015-08-27 Fixed connection error. Needed to close device
2015-09-20 Modified to use callback for app errors
    [blees.h, main.c]
2015-09-30 Power consumption much better now. 582.67uW
2015-10-07 couple more changes to app, icon
2015-10-07 More sensitive to acc & led back
2015-10-08 Option to set device BLE address at flash time
2015-10-11 move sensor drivers to central folder
2015-11-11 working on adding db to blees app
    not working, insert command isn't finishing. softdevice throwing
    assert. not sure why.
    [main.c, nrf_drv_config.h]
2016-01-08 Massively reduced power needs of BLEES
    Steady state of ~1 mA changes to ~6 uA
    GPIOTE interrupts have been changed to Port interrupts rather than
    specific pin interrupts. TWI is disabled while waiting for Light sensor
    to wake up.
2016-01-29 tried to fix signed problem in blees temperature
2016-01-29 actually fixed negative temperatures
2016-02-04 update to light sensor driver
    trying to fix invalid values
    [main.c, tsl2561.c]
2016-02-04 enable gpiote interrupts
2016-02-05 Make movement LED visible
2016-02-07 add id and hide LED
2016-02-09 Added BLEES current trace
    [blees_current_trace.csv]
2016-02-20 blink
    pir board for squall
    [blink.brd, blink.sch]
2016-02-20 moved label
    [blink.brd]
2016-02-20 clean up some driver code
    try to make it more consistent
    functionize the obvious things
2016-02-20 delete old ble apps
    either no longer needed or moved to nrf5x base
    [main.c, nrf_drv_config.h]
2016-03-03 add flag for pir led
2016-03-05 add blink updated zip
    [blink.brd, blink.sch]
2016-03-11 add bom
    [blink_bom.xlsx]
2016-03-13 BLEES Rev D
    Added Pogo-Pin programmer
    [squall-blees-board.brd, squall-blees-board.sch, squall-blees-board_bom.csv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]
2016-03-13 BLEES PCB rev D. Panelized and packaged
    [merge.cfg, squall-blees-board.brd]
2016-04-14 added support to reset accelerometer, added reset prepare for dfu
    [adxl362.c, main.c]
2016-04-22 Update BLEES to enable wireless DFU
2016-05-13 remove enabling dcdc converter, adjust accel
    - less sensitive accelerometer
2016-05-19 Update BLEES app
    Add a sequence number to end of data
    Acceleration data has "currently active" and "in last
    minute modes"
2016-06-07 add first attempt at blink case
    [blink_case.SLDPRT, blink_case_v1.STL]
2016-07-17 Solar BLEES!
    Reads humidity and temperature a sends their data in an advertisement,
    all while harvesting from a solar monjolo
    Still a work in progress
2016-07-26 Added startup delay for sensor
2016-11-21 Added airplane data
    [airplane_environmental_sensing.xlsx]
2016-12-05 Make BOM github compliant
    [squall-blees-board_bom.csv]
2017-02-01 updated PIR sensor part number
    [blink.brd, blink.sch]
2017-06-11 included javascript file
    it at least pop us the list of devices, but I can't test at home

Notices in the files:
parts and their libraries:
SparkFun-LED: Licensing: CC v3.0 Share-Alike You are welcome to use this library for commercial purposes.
